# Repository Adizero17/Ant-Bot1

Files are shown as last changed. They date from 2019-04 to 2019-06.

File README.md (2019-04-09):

# Ant-Bot1
Hallo zusammen und Herzlich Willkommen bei unserem Hochschulprojekt Robots Wars!
In den kommenden Wochen werden wir einen Roboter der AntClass konstruieren und freuen uns dabei auf ein faires Battle mit unseren Kommilitionen.

# SolidWorks CAD-Komponenten
Im Verzeichnis CAD-Daten befinden sich einige SolidWorksBauteile bzw. Baugruppen von Zukaufteilen.

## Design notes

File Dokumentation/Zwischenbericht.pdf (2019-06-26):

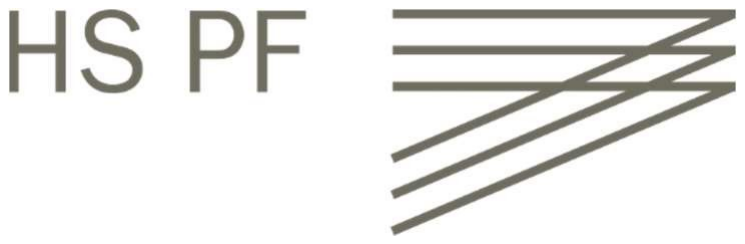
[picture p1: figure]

Projekt Methoden und Kreativität

# Gruppe IT-S3 – Robot Wars Zwischenbericht

Autoren: | Leon Frei – 314332 Tobias Schieler – 314689 Sven Krohn – 314695 Louis Scharr – 314538
Betreuer: | Prof. Alfred Schätter Dipl.-Wirt.-Ing. René Triebenstein
Ort: | Pforzheim
Abgabetermin: | 24.04.2019
Semester: | SS 2019

## Abbildungsverzeichnis

## Inhaltsverzeichnis

## 1 Einleitung

Das diesjährige Projekt der Veranstaltung „Projekt Methoden und Kreativität“ besteht darin, einen Roboter der Ant-Klasse mittels SolidWorks und 3D Druck zu entwickeln. Dieser Prozess wird durch verschiedene Meilensteine begleitet. Angefangen bei der Analyse, über das Konzept und den Prototyp, bis hin zur Fertigung und Präsentation des Endprodukts. Begleitend hierzu sollen die Meilensteile mittels einem Versionsverwaltungssystem kontrolliert und gesichert werden. Zusätzlich zur Analyse und der Entwicklung werden die jeweiligen Meilensteine dokumentiert, sowohl als auch präsentiert. Im folgenden Bericht soll dies dargestellt und erläutert werden.

## 2 Aufgabenstellung und Zieldefinition

Ziel des Projektes ist die Entwicklung und die Herstellung eines Miniatur Roboters der Ant-Klasse mithilfe von begrenzten Möglichkeiten in Material- und Werkzeugwahl. Der Roboter wird im CAD (SolidWorks) entwickelt und konstruiert und anschließend mittels einem 3D Drucker mit FDM-Technologie hergestellt. Dabei soll der Roboter weder die Gewichtsgrenze von 220g, noch die Größe von 10x10x10cm überschreiten. Dazu muss erwähnt werden, dass mögliche Anbauten für den Roboter (z.B. Waffen/Greifer) die Größenabmessungen in geringem Maße überschreiten dürfen. Ein zeitlicher Rahmen ist ebenfalls vorgegeben. Damit im Zusammenhang stehend soll am Ende des Projektzeitraumes ein Wettbewerb unter beiden teilnehmenden Gruppen stattfinden. Die Aufgabe hierbei ist es entweder 3 Tischtennisbälle in der Zone des Gegners zu platzieren, den Gegner bewegungsunfähig zu machen, oder ihn in die Falltür der Arena zu schieben. Um einerseits Versions-Probleme bei der Umsetzung mit dem 3D-Drucker zu vermeiden, als auch um einzelne Bauteile und Meilensteine des Projektes zu verwalten und zu sichern, wird das Versionsverwaltungstool GitHub verwendet, auf welches im späteren Verlauf des Berichts näher eingegangen wird.

## 3 Analyse

Im Folgenden werden alle beeinflussenden Komponenten des Projektes, die zu verwendenden Materialien, die Werkzeuge, die Informationsquellen so wie das Umfeld analysiert.

3.1 Aufgabenstellung
In erster Instanz wurde die gegebene Aufgabenstellung analysiert. Die Aufgabenstellung lautet wie folgt:

„Es soll ein Miniatur-Roboter entwickelt werden, der auf einem 3D Drucker der FDM- Technologie hergestellt werden kann. Dabei soll der Roboter max. 10x10x10cm groß sein und nicht mehr Gewicht als 220g auf die Waage bringen. Der Roboter wird per Fernsteuerung von seinem Piloten gesteuert und hat die Aufgabe seinen Gegner in der Arena bewegungsunfähig zu machen oder in eine der Fall-Türen der Arena zu schieben. Der Antrieb erfolgt über 2 Miniatur Getriebe-Motoren und einem 2S-Lipo-Akku. Die elektronischen Komponenten sind Zukaufteile und werden von der Hochschule gestellt.Der Contest findet bei der Endpräsentation statt.
Der Roboter wird im CAD entwickelt und konstruiert. Um Versions-Probleme bei der späteren Umsetzung mittels 3D-Drucker zu vermeiden soll schon von Projekt-Beginn an das Versionsverwaltungssystem Git die einzelnen Bauteile des Roboters versionieren und sichern.“ ¹

Die Aufgabenstellung beschreibt wie der Contest am Ende der Projektarbeit gewonnen werden kann. Einerseits kann gewonnen werden, indem alle drei Tischtennisbälle in der gegnerischen Zone platziert werden (Methode 1), der Gegner in die Falltür befördert wird (Methode 2), oder der Gegner bewegungsunfähig gemacht wird (Methode 3). Dies führt zu folgender Schlussfolgerung: um die Tischtennisbälle in die gegnerische Zone zu befördern, ist es notwendig eine Vorrichtung zur Befestigung der Bälle zu konstruieren. Diese kann entweder an der Front oder dem Heck des Roboters befestigt werden.

1 https://lms.hs-pforzheim.de/pluginfile.php/75548/mod_resource/content/15/PMK_Projekte_SS_2019.pdf

Methode 2 erfordert Anbauten, mithilfe derer der Gegner in die Falltür geschoben bzw. gedrängt werden kann. Die letzte Methode, Methode 3 erfordert einerseits ein bodenschlüssiges Design des eigenen Roboters, so dass der Gegner den eigenen Roboter nicht einfach weghebeln kann. Andererseits ist es notwendig „Waffen“ und Ersatzteile zu bauen/designen, nicht nur um den Gegner bewegungsunfähig zu machen, sondern auch um eventuell zerstörte Bauteile austauschen zu können.

Als nächster Punkt der Aufgabenstellung ist die Gewichtsbegrenzung zu berücksichtigen. Der Roboter darf maximal ein Gewicht von 220g aufweisen, daher muss zu aller erst berechnet werden, wie viel die bisher bereitgestellten Teile wiegen und wie viel Gewicht somit noch hinzugefügt werden kann. Auf der anderen Seite müssen die Auswirkungen der Gewichtswahl berücksichtigt werden. Ein leichter Aufbau ermöglicht ein schnelleres Manövrieren des Roboters, wobei ein schwerer Aufbau eventuelle Designoptionen ermöglicht und Angriffen des Gegners besser standhält.

Als letzter Punkt der Aufgabenstellung muss noch die Arbeit mit den verschiedenen Programmen (GitHub, SolidWorks) sowie der hohe Organisationsaufwand berücksichtigt werden. Hierbei ist es wichtig eine klare Aufgabenverteilung und einen Zeitplan zu entwickeln.

3.2 Informationsquellen
Bei der Analyse der Informationsquellen gibt es einige grundlegende Dinge, die beachtet werden müssen. Da es sich bei der Konstruktion des Roboters nicht wirklich um ein wissenschaftliches Thema handelt, gibt es hierzu auch keine Fachliteratur, die die Einarbeitung in das Thema erleichtert und eindeutige sowie fundierte Informationen liefert. Aus diesem Grund wurde bei der Informationsbeschaffung hauptsächlich auf Internetseiten zurückgegriffen.
Diese haben zwar den Vorteil, dass die Informationen leicht und schnell zugängig sind, jedoch nicht wissenschaftlich untermauert sind. Ein weiterer Punkt, der sich bei Analyse herausstellte, war dass der Hauptteil der Internetseiten auf Englisch ist. Dies erschwert die Beschaffung von Informationen, da es häufiger zu Verständnisproblemen aufgrund der Sprachbarriere kommen kann, was unter anderem natürlich auch auf das technische Thema und dessen Fremdwörter zurückzuführen ist.

3.2.1 Bildersuche per Google
Als eine erste Quelle zur Beschaffung von Informationen wurde die Google-Bildersucher verwendet. Dies diente hauptsächlich zur Erlangung von Designideen für den Roboter an sich, sowie das Chassi, die möglichen Anbauten sowie Waffen.

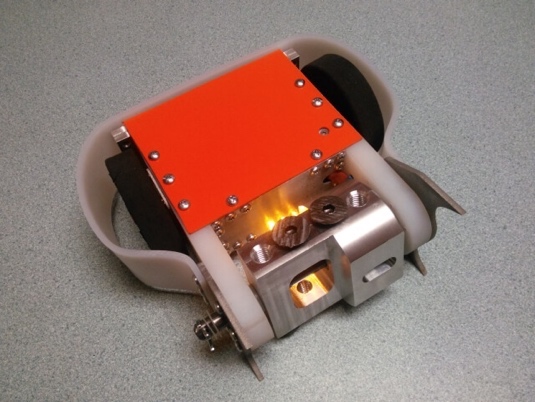
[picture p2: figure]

Abbildung 1: Designidee für Roboter ²
3.2.2 Foren
Eine weitere Informationsquelle waren Internetforen und Verbände (z.B. „German Roboteers Association“). Der Vorteil dieser Foren war vor allem die hohe Dichte an Beiträgen und Informationen rund um das Thema AntBots.

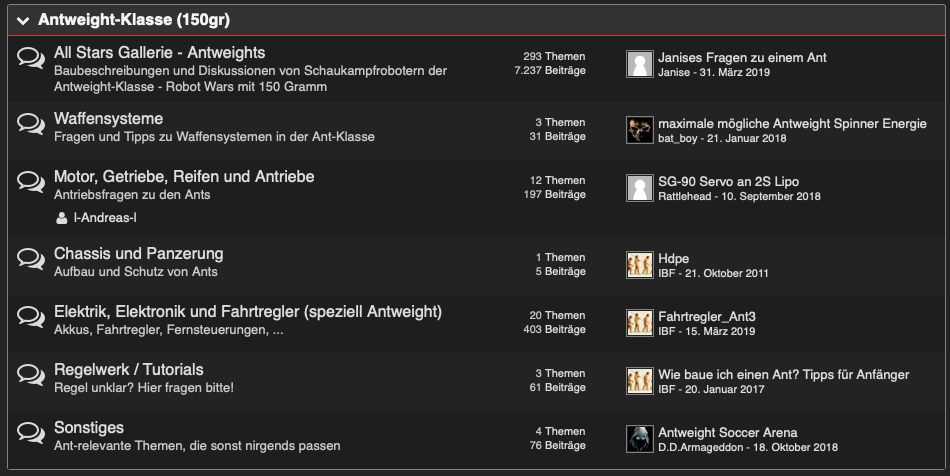
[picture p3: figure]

Abbildung 2: Internetseite German Roboteers Association ³

Die Informationen reichen von einer Galerie mit Designideen, über Beiträge zu den Motoren und der Chassis, bis hin zu speziellen Anleitungen zur Elektronik, gerade für die Ant-Klasse. Ein weiterer Vorteil ist natürlich, dass alle Daten frei zugänglich sind und man sich mit anderen, begeisterten AntBot-Entwicklern austauschen kann. Der Austausch an Informationen erfolgt hierbei sehr schnell, man profitiert außerdem von den Erfahrungen der anderen Entwickler.

2 https://combatrobotics.co.nz/wp-content/uploads/2018/04/3lb-Battle-Bot-Kit.jpg
3 http://forum.roboteers.org/index.php?board-list/&s=514eca6cca9b86eacb0dade5b4f5d3b127892d1e

3.2.3 Thingiverse

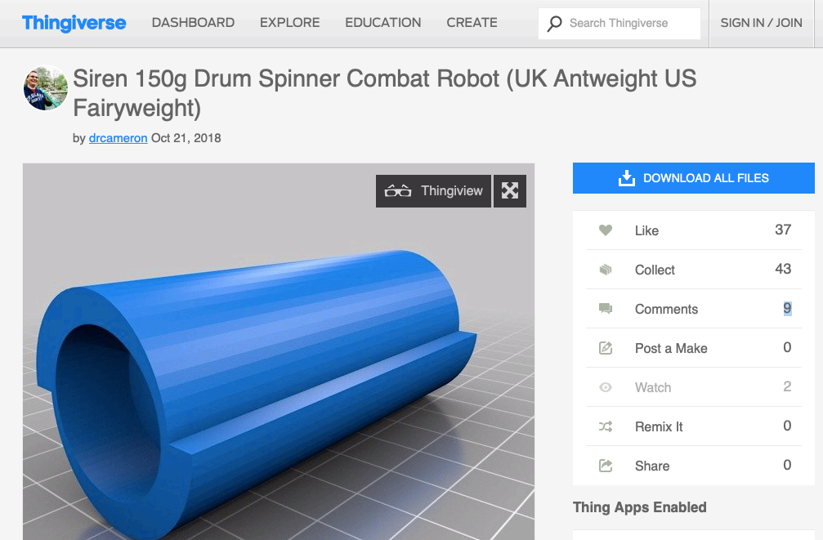
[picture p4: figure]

Abbildung 3: Beitrag zu AntBot auf Thingiverse ⁴
Die Internetseite Thingiverse hat sich als sehr umfangreiche Informationsquelle herausgestellt. Hier sind rund 50 Beiträge zum Thema AntBots zu finden, teilweise auch sehr detailliert. Was vor allem auffällt ist, dass nahezu jeder Beitrag ein Downloadfeld besitzt. Hierüber lassen sich alle angefertigten Zeichnungen als STL-Dateien herunterladen und nutzen. Der Download dieser Dateien ist kostenlos, allerdings besteht die Möglichkeit den Entwicklern eine Spende zukommen zu lassen. Des Weiteren wird auf den Zusammenbau der Roboter eingegangen, welche Teile benutzt wurden und auch wo diese zu erwerben sind. Teilweise werden zusätzlich sogar noch die Einstellungen des 3D-Druckers beschrieben, sowohl als die Verwendung des Materials mit Anwendungshinweisen.

3.2.4 YouTube
Als letztes Informationsmedium wurde die Plattform YouTube genutzt. Hier gibt es sogenannte Videoreihen mit „How to“ Anleitungen zu jedem Schritt der Entwicklung eines Ant-Klasse Roboters. Es wird in den einzelnen Videos auf die Bauweise, das Design, die Waffen sowie die Elektronik eingegangen. Der Vorteil ist natürlich das das Ganze visualisiert ist und man so einen besseren Bezug zum Thema findet.

4 https://www.thingiverse.com/thing:3168700

Es wird sehr ausführlich auf jedes Thema eingegangen, zudem sind Links zu allen Bauteilen angegeben. Auch hier besteht die Möglichkeit sich mit den Entwicklern in Verbindung zu setzen, um mehr über Informationen allgemein bzw. das Projekt zu erhalten. Außerdem ist auch bei mancher dieser Videoreihen die Möglichkeit gegeben, einzelne, bereits designte Teile herunterzuladen.

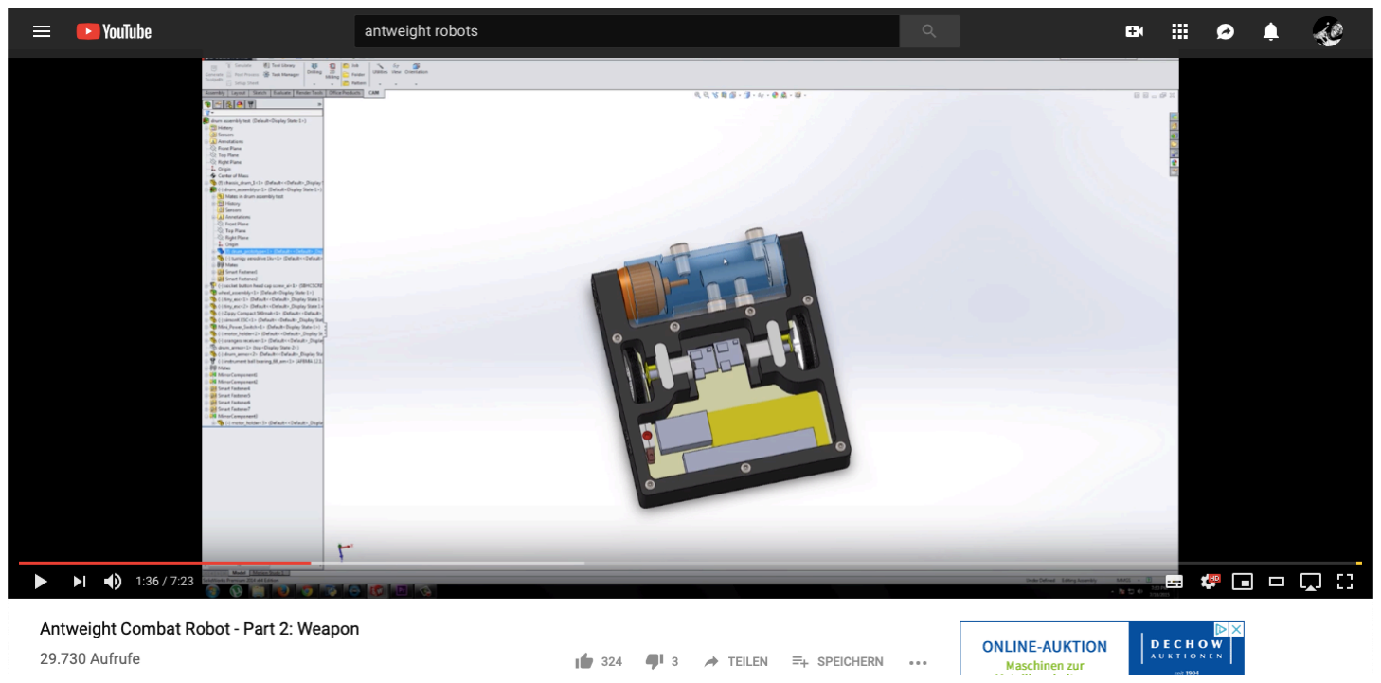
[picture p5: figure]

Abbildung 4: Video einer Videoreihe zum Aufbau eines AntBots ⁵

3.3 SolidWorks
SolidWorks ist ein Konstruktionsproramm, mit dem detaillierte Zeichnungen möglich sind. Hier können sowohl 3D- als auch 2D-Konstruktionen erstellt werden. Außerdem sind die generierten Dateiformate mit der Software des zur Verfügung gestellten 3D-Druckers kompatibel. Bauteile können im Programm direkt zu einer Baugruppen zusammengefügt werden und Änderungen werden hier auch direkt ersichtlich. Für den Windows User ist der Aufbau benutzerfreundlich gestaltet, da sich die Oberfläche an der Windows-Steuerung orientiert.⁶

3.4 GitHub
GitHub ist ein Onlinedienst, welcher über diverse Funktionen verfügt und zahlreiche Vorteile bezüglich eines Projektes, wie es das Konstruieren eines Ant-Roboters darstellt, bietet. Aus diesem Grund nimmt das Verwaltungstool Github im Projekt eine zentrale Rolle ein. Durch die öffentliche Bereitstellung von Daten und Depositories diverser Entwickler von der ganzen Welt kann man gezielt nach Anregungen und Ideen suchen.

5 https://www.youtube.com/watch?v=R5MbYqHyuIM&t=114s 6 https://www.solidworks.com/de

Man hat zudem die Möglichkeit, bereits konstruierte Teile als „.SLDPRT“ herunterzuladen, was das einfache Öffnen der Datei mit Programmen wie Solid Works ermöglicht. Hierdurch kann man, sollten die Teile den eigenen Ansprüchen gerecht werden, enorm an Zeit sparen. Github dient außerdem als Versionsverwalter von Projekten. Dies bedeutet, dass Backups und Zwischenstände von allen konstruierten Bauteilen erzeugt werden, sodass kein Datenverlust auftritt. Weiter dient es als Schnittstelle, was das Zusammenführen von Ergebnissen und das Sammeln aller relevanten Daten an einem Ort äußert komfortabel macht. Entwickler haben so, durch Absprechen und Arbeitsteilung, zudem die Möglichkeit gleichzeitig an einem Projekt zu arbeiten.

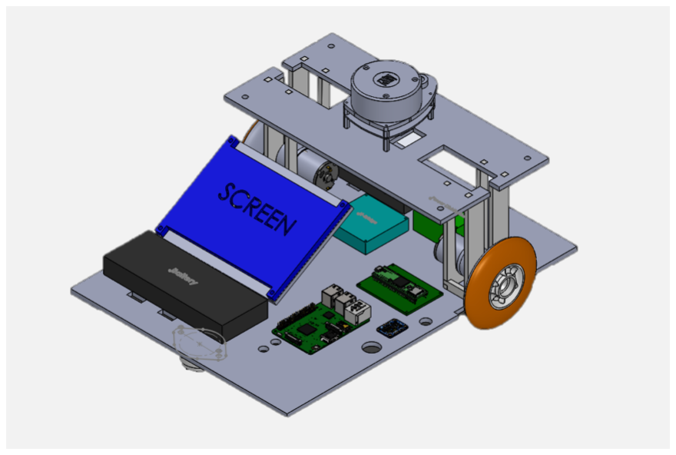
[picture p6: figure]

Abbildung 5: Auf Github hochgeladener Beispielhafter Roboter der Ant-Klasse ⁷

7 https://github.com/thedch/indoor-autonomous-system-cad/blob/master/RobotImages/RobotIsometric.png

3.5 Bauteile
Bei der Bauteilanalyse muss zwischen den elektrischen sowie den mechanischen Komponenten unterschieden werden. Die bisher bereitgestellten Bauteile sind zwei Gleichstrom Getriebemotoren, ein Speed Controller, zwei Pololu Räder und eine Stützkugel. Im Folgenden soll näher auf die einzelnen Bauteile eingegangen werden.

3.5.1 Gleichstrom Getriebemotor
Der Getriebemotor weißt eine Größe von 25x12x10 mm auf sowie ein Gewicht von 10 g. Zudem läuft der Motor unter einer Betriebsspannung von 6 V. Der Motor an sich ist ein Bürstenmotor und übergibt die Kraft an das Getriebe mit einer
Übersetzung von 1:200. Der Getriebetyp ist Metall. Die Kraft wird

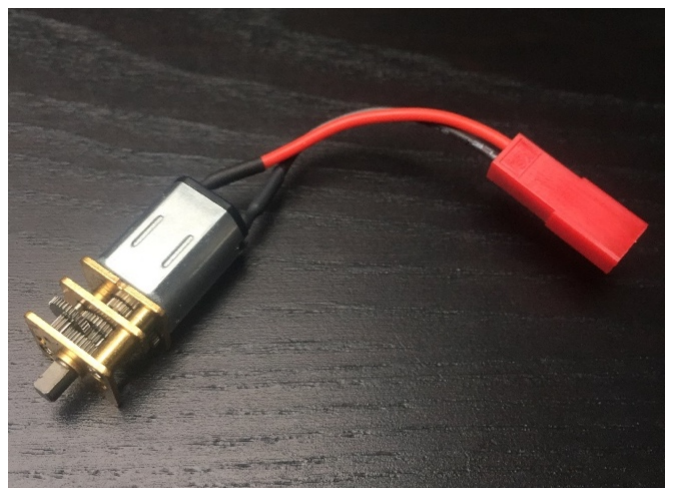
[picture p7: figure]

vom Getriebemotor an das Getriebe weitergegeben und dann in dabei in das Verhältnis 1:200 übersetzt. Diese Kraft wird dann weiter auf die Räder übertragen. ⁸

3.5.2 Micro Dual Bi-Directional Speed Controller

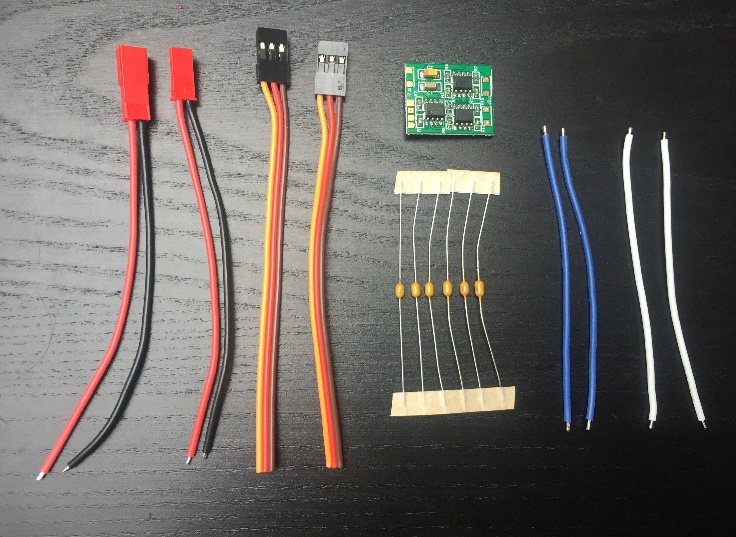
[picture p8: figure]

Abbildung 7: Speed Controller Quelle: eigene Aufnahme

8 https://eckstein-shop.de/V-TEC-Micro-DC-Motor-Gleichstrom-Getriebemotor-10x8mm-10x12mm-12x13mm-3V-6V-17-560RPM

Abbildung 6: Gleichstrom Getriebemotor Quelle: eigene Aufnahme

Der Speed Controller weißt eine Größe von 19x23x5 mm auf und ein Gewicht von 6 g. Zudem besitzt der Speed Controller und einer Eingangsspannung zwischen 4,2 V – 9,6 V sowie eine Stromstärke von 6 A.
Die elektronische Spannungsregelung liegt bei 5V1A. Die PWD-Frequenz beträgt 250 Hz. ⁹
Diese Platine besitzt einen Mischer, mit dem es möglich ist den Roboter mit einer Fernbedienung zu steuern. Das Signal (siehe Abbildung 7) bestimmt hier Motordrehzal (vorwärts/rückwärts), das Signal 2 die Richtung (links/rechts). ¹⁰

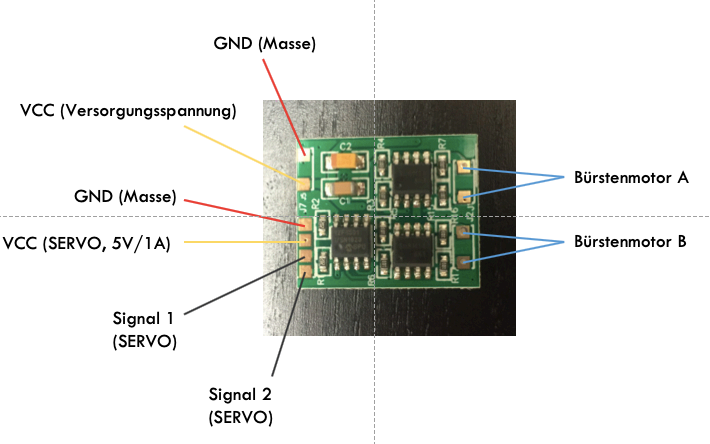
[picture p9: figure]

Abbildung 8: Platine

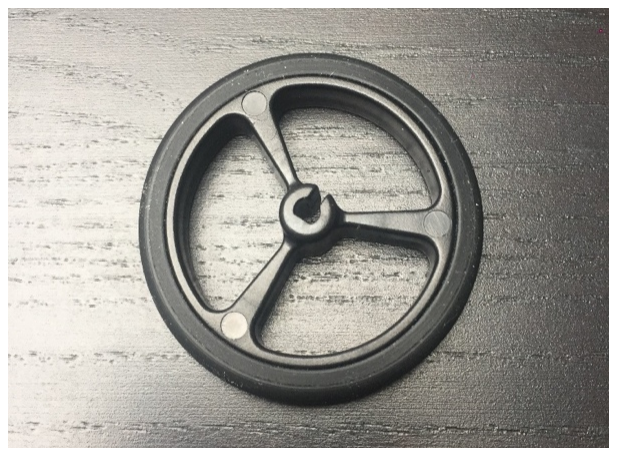
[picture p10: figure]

3.5.3 Pololu Rad
Insgesamt wurden 2 Pololu Räder zu Verfügung gestellt. Sie weißen beide eine Größe von 40x7 mm auf sowie ein Gewicht von jeweils 4 g. Die Räder sind Kunststoff gefertigt und mit Silikon besetzt. Sie dienen der Fortbewegung des AntBots. ¹⁰

9 https://www.banggood.com/2S6A-Micro-Dual-Bi-Directional-Speed-Controller-for-Tank-Crawler-and-Boat-without-Brakep-1032413.html?ID=520184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 10 https://github.com/merlin1031/AntBots-2019

Abbildung 9: Pololu Rad
Quelle: eigene Aufnahme

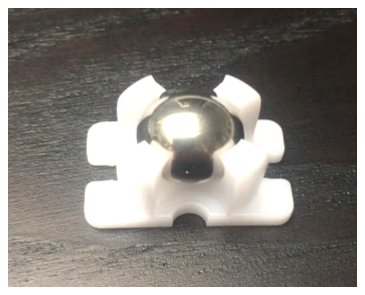
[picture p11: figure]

3.5.4 Stützkugel
Das letzte, bereitgestellte Bauteil ist die Stützkugel bzw. eine Kugelrolle. Sie weißt eine Größe von 24x16x16 mm auf und wiegt 9 g. Sie ist aus Metall gefertigt und dient als Stützkugel/Stützrad für den AntBot. ¹⁰

3.6 Fertigungsverfahren
3.6.1 Löten
Da für den Aufbau und die Funktionsweise des Roboters eine Platine benötigt wird, ist es notwendig bestimmte Teile zu löten. Das Löten ist ein thermisches Verfahren, bei dem Werkstoffe stoffschlüssig zusammengefügt werden. Der Unterschied zum Schweißen besteht hierbei, dass die Liquidustemperatur der beiden zu verbindenden Komponenten nicht überschritten werden darf. Insgesamt gibt es drei verschiedene Lötarten: das Weichlöten (Liquidustemperatur bis 450 Grad Celsius), das Hartlöten (über 450 Grad Celsius) und das Hochtemperaturlöten (mehr als 900 Grad Celsius). Für das Projekt des AntBots wird das Weichlötverfahren genutzt. Beim Löten muss darauf geachtet werden, dass die Lötstellen sauber sind und dass ebenfalls keine Lotreste außerhalb der Lötstellen festsitzen. Außerdem sollte nicht zu viel Lot verwendet werden, aber auch nicht zu wenig, da sonst die Funktionsweise der Platine beeinträchtigt werden kann. Als letztes sollten auch keine kalten Lötstellen entstehen, da auch hier keine stoffschlüssige Verbindung zwischen Lot und Fügepartner entsteht. ¹¹

3.6.2 3D-Druck

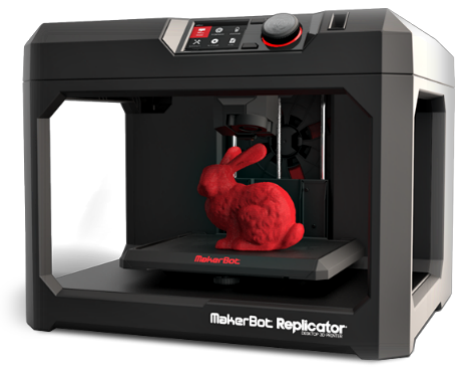
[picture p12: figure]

Abbildung 11: Makerbot 5th Generation ¹²

11 http://www.gasloetkolben.com/welche-loetarten-gibt-es/ 12 https://www.3dhubs.com/s3fs-public/Makerbot%20Replicator%205th%20Gen%202.png

Abbildung 10: Stützkugel
Quelle: eigene Aufnahme

Für die Herstellung einzelner Bauteile steht der Makerbot 5th Generation (Abb. 10) zur Verfügung. Hierbei handelt es sich um einen 3D- Drucker mit einem Düsendurchmesser von 0,4 mm. Durch die Begrenzung des Bauteils auf 10x10x10 cm besteht keine Gefahr beim Drucken an die maximale Bauraumgröße mit 25x20x15 cm des 3D-Druckers zu geraten.

Sollte ein sehr filigranes oder optisch hochauflösendes Bauteil für die Konstruktion des AntBots von Nöten sein, kann die Schichtdicke von 0,1 mm auf 0,01 mm heruntergefahren werden.
Als Datengrundlage kann der Makerbot 5th Generation sowohl STL, OBJ, THING als auch Makerbot Dateien verarbeiten. Lediglich alte Dateitypen wie X3G lassen sich leider nur sehr aufwendig konvertieren und sind dann immer noch nicht sehr kompatibel.

Vor dem Druck müssen die über SolidWorks erstellten Bauteile in einer von Makerbot zur Verfügung gestellten Software hochgeladen und vorbereitet werden. Hierbei wird zum Beispiel Stützmaterial für den Druck in das Bauteil eingefügt. Am Drucker selbst besteht die Möglichkeit über USB, WLAN oder LAN zu drucken, was eine Flexibilität darstellt. Als weiterer Vorteil ist zu sagen, dass der Makerbot 5th Generation erkennt, wenn Filament ausgeht und daraufhin der Druck direkt gestoppt wird. So kann es in diesem Bereich zu keinen Komplikationen kommen.
Für die Fertigung ist auch die überdurchschnittliche Verfahrenszeit zu berücksichtigen. Hier muss darauf geachtet werden, dass frühzeitig mit einem Druck begonnen wird. ¹³ ¹⁴

13 https://www.pcwelt.de/produkte/Makerbot-Replicator-Fuenfte-Generation-im-Test-3D-Drucker-9692579.html 14 https://3ddrucker.de/shop/pi.php/MakerBot-3ddrucker/MakerBot-Replicator-5th-Generation/3D-Drucker-MakerBot-Repli-

cator-5-Generation.html

3.6.3 Laserschneiden
Zusätzlich zum 3D-Drucker besteht auch die Möglichkeit zur Verwendung eines Laserschneiders. Nahezu jeder Werkstoff lässt sich mithilfe des Laserstrahles schneiden, hinzu kommt die hohe Präzision des Lasers. Je nach Werkstoff wird ein anderes Verfahren verwendet. Es wird zwischen dem Laserschmelzschneiden, dem Laserbrennschneiden und dem Lasersublimierschneiden unterschieden. Der beim Schneiden entstehende Schneidspalt ist nur minimal größer als der Laserstrahl selbst, womit sich Toleranzen von +/- 0,1 mm/m erzielen lassen. Ebenfalls abhängig von der Dicke des Materials sowie dem Werkstoff an sich ist die Schnittgeschwindigkeit von bis zu 40 m/min. ¹⁵

3.6.4 Kleben
Ebenso wie das Löten, ist das Kleben ein Fügeverfahren. Beim Kleben werden zwei Werkstoffe stoffschlüssig miteinander verbunden. Eine entscheidende Rolle hierbei spielt die Benetzung der zu klebenden Oberflächen. Ebenfalls zu berücksichtigen sind Adhäsion und Kohäsion. Adhäsion bezeichnet die Haftkräfte an den Kontaktflächen der zu klebenden Stoffe, wobei Kohäsion die Summe der Bindekräfte zwischen den einzelnen Molekülen des Klebers beschreibt. Eine ideale Klebeverbindung ist gegeben, wenn beide diese Faktoren in etwa gleich groß sind.¹⁶

## 4 Konzept

Um generell ein Projekt jeglicher Art zu realisieren, ist es stets enorm wichtig, zunächst die Aufgabenstellung, sowie die Rahmenbedingungen klar zu definieren und sich diese vor Augen zu führen. Ohne diesen Schritt läuft man Gefahr, bestimmte Richtlinien zu missachten oder schlicht nicht das volle Potential seiner Ideen auszuschöpfen. Zudem ist es unabdinglich, sich seiner Möglichkeiten und Ressourcen bewusst zu sein. Basierend auf diesen Daten lässt sich mithilfe verschiedener Instrumente ein Konzept erstellen, welches eine ideale Ausgangslage für einen optimalen Projektablauf gewährleistet.

15 https://www.laserschneiden-marktplatz.de/laserschneiden-grundlagen 16 https://www.fachwissen-technik.de/verfahren/kleben.html

Da es sich beim Erstellen eines Roboters der Ant-Klasse um ein sehr technisches Projekt mit einem hohen Fokus auf das Themengebiet der Konstruktion handelt, ist es enorm wichtig, alle Schritte gut zu planen, um möglichst effizient und effektiv zu arbeiten. Um diesen Ansprüchen nachzukommen, wurden zunächst alle potentiellen Möglichkeiten für den Aufbau des Roboters mit Hilfe des morphologischen Kastens erfasst. Durch die visuelle Veranschaulichung aller Ausprägungen und Parameter ist es wesentlich einfacher, den für die jeweiligen Anforderungen perfekten Aufbau eines Projektes zu wählen.

5.1 Antriebskonzept

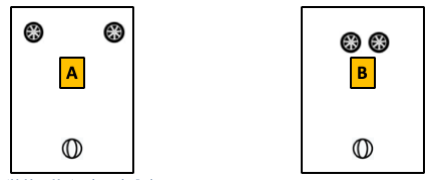
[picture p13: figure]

Abbildung 12: Anordnung der Räder
Quelle: eigene Darstellung
Für den Antrieb des Ant-Roboters sind neben den Elektronikbauteilen vor allem die beiden Räder und das Kugellager, welches als drittes Rad dient, relevant. Durch diese Bauteile findet letztendlich die Energieübertragung der elektronischen Bauteile auf den Untergrund statt. Der Antrieb des Roboters erfolgt, wie bereits erwähnt, durch zwei Elektromotoren, welche mit den Rädern verbunden sind, um eine Kraftübertragung zu realisieren. Um ein optimales Handling und Steuern des Roboters zu gewährleisten, wird das Kugellager (drittes Rad) am hinteren Teil des Roboters platziert. Der vordere Teil des Roboters wird dementsprechend dadurch definiert, dass an ihm die beiden normalen Räder montiert sein werden. Dieser Aufbau des Roboters mit Frontantrieb durch die beiden Räder vorne und einem Stützrad hinten ermöglicht es, den Roboter mit maximaler Kontrolle zu steuern. Bei der Positionierung der beiden Räder ist es besonders wichtig, einen optimalen Abstand zwischen diesen zu realisieren. Montiert man die beiden Räder, wie bei Abbildung 12 B zu nah aneinander, leidet nicht nur das Gleichgewicht des Roboters darunter.

Es wird ebenfalls weitaus schwerer, diesen zu steuern, da vor allem das Fahren von Kurven, aufgrund des kleineren Wendekreises ein Problem darstellen würde. Eine leicht eingerückte Lage der Reifen gewährleistet eine optimale Stabilität, Bodenhaftung, sowie das einfachste Steuern des Roboters. Zudem bietet dies Schutz vor potentiellen Angriffen des anderen Roboters, da die Räder mitunter eine der größten Schwachstellen darstellen. Das Stützrad, welches sich am hinteren Teil befinden wird, sollte natürlich idealerweise zentral positioniert sein, um ein gleichmäßiges Lenkverhalten zu ermöglichen.

Die Räder werden direkt mit den beiden Elektromotoren verbunden sein. Dies bedeutet im Umkehrschluss, dass eine Konstruktion die beiden Motoren fixieren muss, um eine optimale Stabilität zu erreichen. Diese Konstruktion wird voraussichtlich mit den Motoren verschraubt.

5.2 Lage des Akkus und der Elektrokomponenten

Wie bereits in der Analyse beschrieben, wird der Roboter über zwei Elektromotoren verfügen, welche den Roboter antreiben und einen weiteren Elektromotor, welcher für die Funktion etwaiger Zusatzanbauten benötigt wird. Ferner wird ein Akku im Roboter montiert sein und eine Platine, welche die Programmierung des Roboters beinhaltet und die Steuerung mit Hilfe einer Fernsteuerung ermöglicht. Dadurch, dass der Roboter auf einer Seite eine V-Form mit dem Zweck der Ballführung aufweisen wird, ist eine Wahl der Lage der elektronischen Komponenten nur im mittleren Bereich, bzw. auf der anderen Seite der Ballführung möglich.

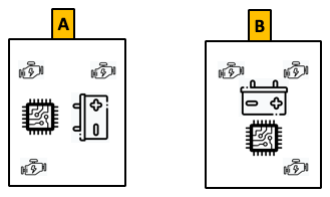
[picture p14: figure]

Abbildung 13: Lage des Akkus und der Elektrokomponenten Quelle: eigene Darstellung

Die beiden Elektromotoren, welche die Räder antreiben habe natürlich ihre feste Position. Lediglich bei der Platzierung des Akkus, sowie der Platine herrscht eine gewisse Freiheit. Um die Stabilität des Roboters nicht einzuschränken, ist es zunächst wichtig, die beiden Bauteile so zu platzieren, dass eine gleichmäßige Gewichtsverteilung herrscht. Da der Akku mit 35 Gramm etwas schwerer ist als die Platine, sollten beide Bauteile auf einer Linie angeordnet sein, wie in Abbildung 13B zu sehen ist. Fixiert werden der Akku und die Platine auf der Grundplatte, welche die Basis des Roboters darstellt. Wichtig für die Positionierung des Akkus ist es, die Möglichkeit zu besitzen, diesen zu wechseln.

Dies bedeutet, dass der Akku durch keine Kabel oder Bauteile verdeckt sein darf, um ein leichtes ein- und ausbauen zu ermöglichen. Das letzte Elektronikbauteil stellt den Antrieb für den Zusatzanbau dar, welches möglichst nahe an diesem montiert sein sollte, um ein kompliziertes Innenleben des Roboters zu vermeiden.

5.3 Chassis-Formen und Ballführung
Die Chassis Form ist womöglich der wichtigste Bestandteil des Konzeptes, da sie die Basis des Roboters darstellt. Sie besteht aus der Grundplatte, welche die Fixierung der elektrischen Bauteile ermöglicht, sowie den Wänden und dem Innenleben, welche für Stabilität sorgen und Schutz vor dem gegnerischen Roboter bieten. Ein weiterer wichtiger Parameter, welcher auf keinen Fall vernachlässigt werden darf, ist das Gewicht des Roboters, welches auf 220g limitiert ist. Aufgrund dessen ist es enorm wichtig, so wenig Material wie möglich für die Grundplatte aufzuwenden. Eine Konstruktion der Grundplatte mit Rillen und dünnen „Stäben“, anstatt einer vollausgefüllten Fläche ist die logische Konsequenz dieser Überlegung. Da man später in der Lage sein soll, wie in „1.2 Lage der Elektrokomponenten“ bereits beschrieben, den Akku zu wechseln, bietet eine Steckverbindung zum Verschluss des Rahmens eine optimale Lösung.
Wie in der Analyse der Aufgabenstellung beschrieben, wird der Roboter in der Lage sein einen Ball zu führen und von Punkt A nach Punkt B zu „transportieren“. Dies bedeutet, dass die Grundplatte die Form einer Ballführung aufzeigen wird. Die simpelste Möglichkeit eine Führung für einen Ball zu realisieren, ist es, eine Art „V-Form“ zu erzeugen.

Diese soll den Vorteil einer Fixierung durch wenig Spielraum bieten und ein Verlust des Balles während der Roboter in Bewegung ist, vermeiden. Grundsätzlich hat man die Möglichkeit eine solche Form auf beiden Seiten des Roboters einzuplanen. Da jedoch nur in eine Richtung effektiv beschleunigt werden kann, würde es wenig Sinn machen, auf der Rückseite eine solche Form zu realisieren.

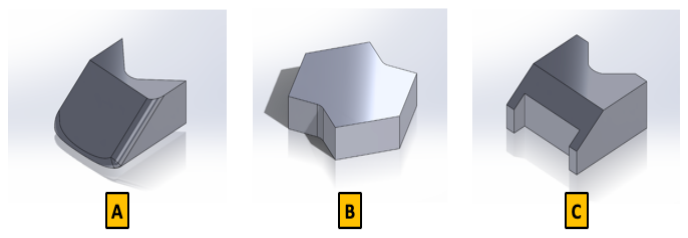
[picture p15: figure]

Abbildung 14: Chassis-Formen und Ballführung
Quelle: eigene Darstellung
Neben der Ballführung wird es eine Zusatzanbaute geben, welche zum Ziel haben wird, den gegnerischen Roboter auszuschalten. Da für den Zusatzanbau verschiedene Möglichkeiten zur Auswahl stehen, sehen dementsprechend auch die Chassis der Roboter-Modelle verschieden aus. Wichtig ist, dass die Fläche, an welcher später der Zusatzanbau angebracht sein wird, schon die zur optimalen Montage vorgesehen Form bietet.

5.4 Zusatzanbauten

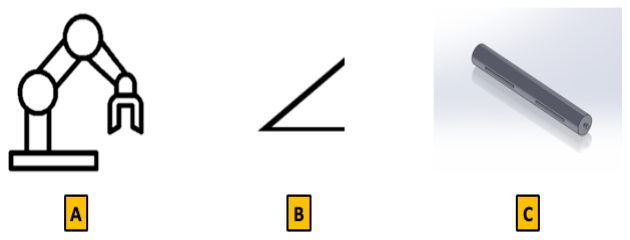
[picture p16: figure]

Abbildung 15: Möglichkeiten der Zusatzanbauten Quelle: eigene Darstellung

Der Zweck des Zusatzanbaus soll es vor allem sein, den Gegner durch eine gezielte Bewegung auszuschalten oder bewegungsunfähig zu machen. Nachdem auch hier durch brainstormen und Erstellung des morphologischen Kastens einige Ideen gesammelt und mögliche Konzepte betrachtet wurden, ließen sich letztendlich drei Konstruktionen herausfiltern. Der wohl vielversprechendste Ansatz ist eine Rolle (Abbildung 15C) mit abstehenden Ausprägungen, welche mit einem elektrischen Motor zur Rotation gebracht werden soll.

Eine dazu passende Chassis-Form ist in Abbildung 14C zu sehen. Diese Rolle bietet vor allem den Vorteil, bei schneller Rotation eine hohe Zerstörungskraft zu entfalten. Zudem ist der Einbau relativ simpel und platzsparend. Leider muss die Rolle relativ schwer sein, um wirklich in der Lage sein zu können, beim Gegner Schaden anzurichten.

Eine weitere Möglichkeit wäre, wie in Abbildung 15B zu sehen ist, eine Art Rampe zu entwerfen, welche den Gegner umwerfen soll. Die dritte Option ist ein Greifer, welcher sowohl dazu eingesetzt werden kann, den Gegner anzugreifen, wie auch den Ball zu greifen und zu transportieren.

5.5 CAD-Entwurf

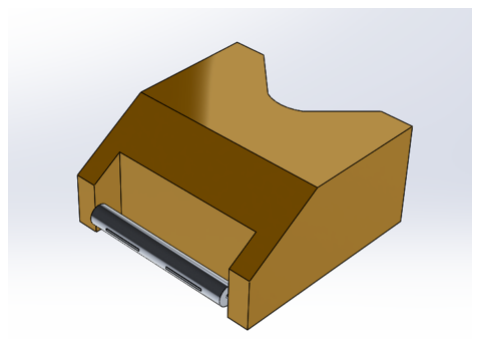
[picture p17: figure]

Abbildung 16: CAD-Entwurf
Quelle: eigene Darstellung
Nachdem anhand des morphologischen Kastens jeweils die besten Ausprägungen und Parameter gewählt wurden, ergibt sich für den Roboter das auf Abbildung 16 zu sehende Konzept. Der Entwurf wurde in Solid Works realisiert und lässt auf der Vorderseite des Roboters die Ballführung erkennen, welche die bereits beschriebene V-Form aufweist. Auf der Rückseite befindet sich die Rolle mit Ausprägungen, welche als Waffe dienen soll.

## 6. Fazit

Die wohl größte Schwierigkeit beim Konzept war die Erarbeitung der Zusatzanbauten mit Einbeziehung des Maximalgewichtes. Da durch die Elektronikbauteile, sowie die Chassis-Formen bereits ein beträchtlicher Teil des Gewichtes in Anspruch genommen wird, ist man bei der Konstruktion des Zusatzanbaus bereits eingeschränkt. So liegt das Hauptaugenmerk bei der Teileanfertigung stets auf möglichst geringer Materialaufwendung.

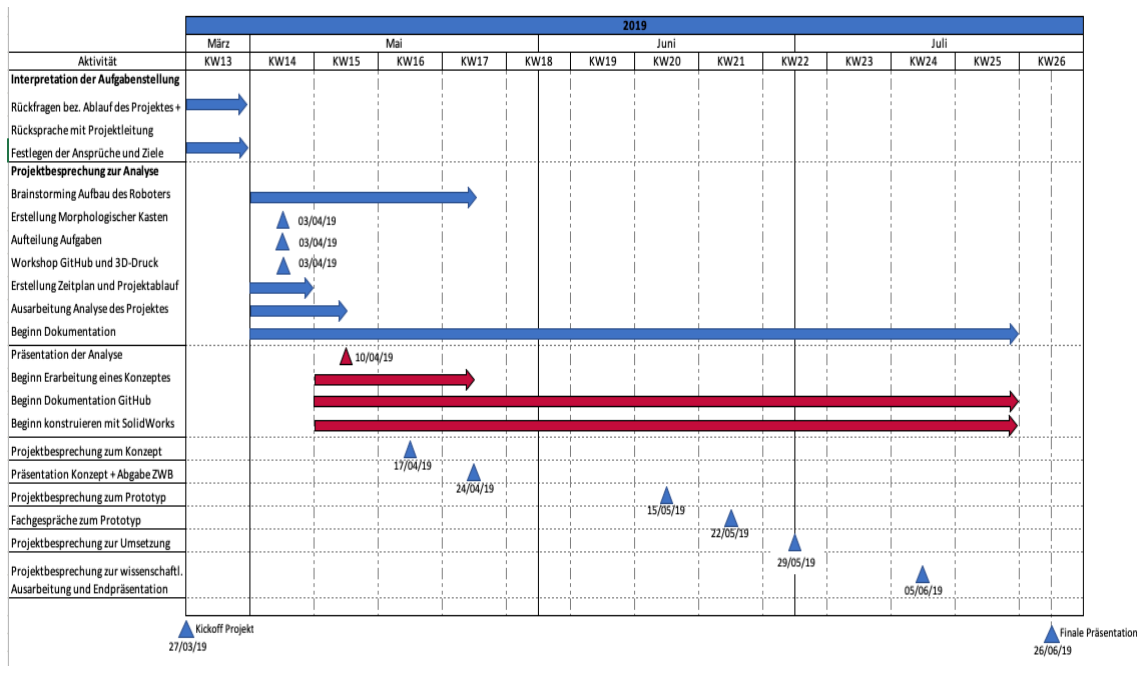
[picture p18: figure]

Abbildung 17: Zeitplan des Projektes
Quelle: eigene Darstellung
Im weiteren Projektverlauf wird basierend auf dem hier beschriebenen Konzept ein erster Prototyp mit Hilfe des 3D Druckes realisiert. Parallel findet die Konstruktion weiterer Bauteile in Solid Works inklusive Dokumentation auf GitHub statt. Außerdem wird begonnen, sich in weitere Fertigungsverfahren, wie z.B. das Löten einzuarbeiten.

## Literaturverzeichnis

[1] Prof. Alfred Schätter, „Hochschule Pforzheim – Moodle – BAE3250“, https://lms.hspforheim.de/pluginfile.php/75548/mod_resource/content/15/PMK_Projekte_SS_2019.pdf, [Online], 21.04.2019
[2] Combat Robotics, „Battle Bot Kit“, https://combatrobotics.co.nz/wp-content/uploads/2018/04/3lb-Battle-Bot-Kit.jpg, [Online], 21.04.2019
[3] German Roboteers Association, „Forum“, http://forum.roboteers.org/index.php?board-list/&s=514eca6cca9b86eacb0dade5b4f5d3b127892d1e, [Online], 21.04.2019
[4] Thingiverse, „Siren 150g Drum Spinner Combat Robot“, https://www.thingiverse.com/thing:3168700, [Online], 21.04.2019
[5] Robert Cowan, „YouTube - Antweight Combat Robot - Part 2: Weapon“, https://www.youtube.com/watch?v=R5MbYqHyuIM&t=114s, [Online], 21.04.2019
[6] DASSAULT S4STEMES, „Solid Works“, https://www.solidworks.com/de, [Online], 21.04.2019
[7] Adam Ames, „GitHub“,
https://github.com/thedch/indoor-autonomous-system-cad/blob/master/RobotImages/RobotIsometric.png, [Online], 21.04.2019
[8] Eckstein Komponente, “Eckstein-Shop”, https://eckstein-shop.de/V-TEC-Micro-DC-Motor-Gleichstrom-Getriebemotor-10x8mm-10x12mm-12x13mm-3V-6V-17-560RPM, [Online], 21.04.2019
[9] Banggood, “Banggood.com”, https://www.banggood.com/2S6A-Micro-Dual-Bi-Directional-Speed-Controllerfor-Tank-Crawler-and-Boat-without-Brake-p-1032413.html?ID=520184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, [Online], 21.04.2019
[10] René Triebenstein, “GitHub”,
https://github.com/merlin1031/AntBots-2019, [Online], 21.04.2019
[11] WordPress, „Gasloetkolben im Test“, http://www.gasloetkolben.com/welche-loetarten-gibt-es/, [Online], 21.04.2019

[12] 3DHubs, „Makerbot 5th Generation“, https://www.3dhubs.com/s3fs-public/Makerbot%20Replicator%205th%20Gen%202.png, [Online], 21.04.2019
[13] PCWelt, „Makerbot Replicator Fünfte Generation im Test“, https://www.pcwelt.de/produkte/Makerbot-Replicator-Fuenfte-Generation-im-Test-3D-Drucker-9692579.html, [Online], 21.04.2019
[14] 3DDrucker.de, „MakerBot 5th Generation“, https://3ddrucker.de/shop/pi.php/MakerBot-3ddrucker/MakerBot-Replicator-5th-Generation/3D-Drucker-MakerBot-Replicator-5-Generation.html, [Online], 21.04.2019
[15] Laserschneiden Marktplatz, „Grundlagen und Einordung der Laserschneidtechnik“,
https://www.laserschneiden-marktplatz.de/laserschneiden-grundlagen, [Online], 21.04.2019
[16] Fachwissen Technik, „Kleben“, https://www.fachwissen-technik.de/verfahren/kleben.html, [Online], 21.04.2019

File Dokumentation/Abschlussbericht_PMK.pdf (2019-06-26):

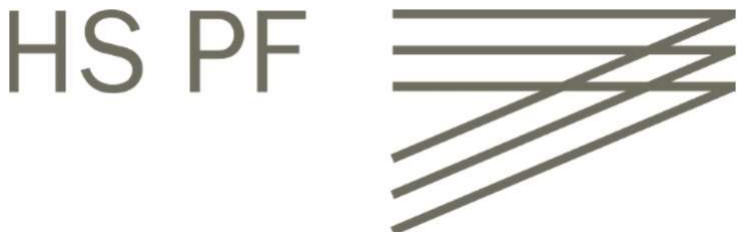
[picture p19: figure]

Projekt Methoden und Kreativität

# Gruppe IT-S3 – Robot Wars

# Abschlussbericht

Autoren: | Leon Frei – 314332 Tobias Schieler – 314689 Sven Krohn – 314695 Louis Scharr – 314538
Betreuer: | Prof. Alfred Schätter Dipl.-Wirt.-Ing. René Triebenstein
Ort: | Pforzheim
Abgabetermin: | 26.06.2019
Semester: | SS 2019

## Abbildungsverzeichnis

Abbildung 1: Konzept | 4
Abbildung 2: Prototyp | 5
Abbildung 3: Grundkörper Prototyp | 6
Abbildung 4: Verbauung der Walze | 6
Abbildung 5: Zusatzanbau Walze Prototyp | 7
Abbildung 6: Leichtbau des Grundkörpers | 8
Abbildung 7: Radkasten Draufsicht | 8
Abbildung 8: Überarbeitetes Konzept der Walze | 9
Abbildung 9: Überarbeitetes Konzept Innenleben Walze | 10
Abbildung 10: Stützring | 10
Abbildung 11: Altes Konzept Innenleben Walze | 10
Abbildung 12: Finaler Roboter der Ant-Klasse | 13
Abbildung 13: Explosionszeichnung Endergebnis | 15
Abbildung 14: Elektronischer Schaltplan | 16

## Tabellenverzeichnis

Tabelle 1: Gewichtsübersicht | 11
Tabelle 2: Gewichtsübersicht nach Überarbeitung der Bauteile | 12

## Inhaltsverzeichnis

## 1 Einleitung

Das Projekt der Veranstaltung „Projekt Methoden und Kreativität“ bestand darin, einen Roboter der Ant-Klasse zu entwickeln. Der Roboter unterstand dabei Bemaßungsgrenzen von 10x10x10 cm und einer Gewichtsgrenze von 220 g. Der abschließende Wettkampf soll hierbei entweder durch die Kampfunfähigkeit des Gegners oder der Platzierung dreier Tischtennisbälle im gegnerischen Feld gewonnen werden. Im folgenden Bericht wird die Umsetzung des Ant-Bots auf der Grundlage des Konzeptes und des Prototyps, der Verbesserungsprozess sowie der fertige Roboter dargestellt und erläutert.

## 2 Entwicklung des Roboters

2.1 Konzept

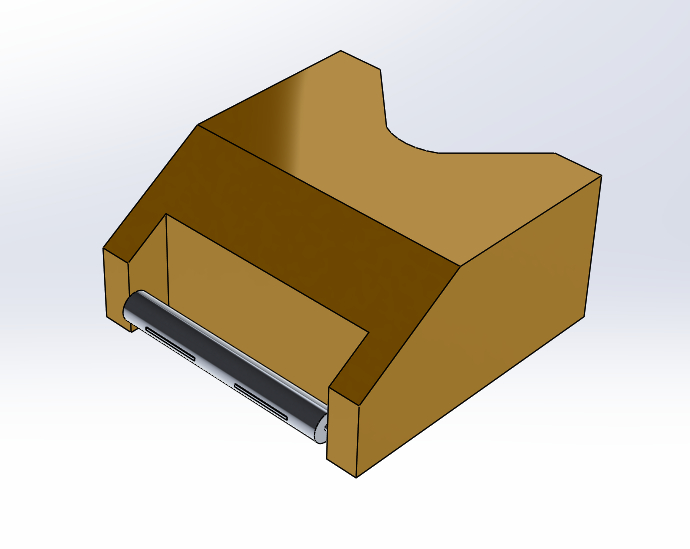
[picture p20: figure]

Abbildung 1: Konzept
Das Konzept diente als Grundlage für die Phase der Umsetzung bzw. für die Entwicklung des Prototyps. Bei der Entwicklung des Konzeptes wurden die ausgewählten Ausprägungen des morphologischen Kastens (siehe Anhang) umgesetzt. Bei der Ballführung wurde eine Dreiecksform mit einer Rundung kombiniert, um den Ball einerseits besser einfangen zu können und andererseits mithilfe der Rundung sicher führen zu können. Als Zusatzanbau wurde ein drehendes Element gewählt, welches als Walze zu erkennen ist (Abb. 1).

Der Verbau der Räder und des Stützrades ist in Abb. 1 nicht zu erkennen, jedoch wurde sich darauf geeinigt die Stützkugel hinten und die Polulu-Räder vorne anzuordnen, um so den Schwerpunkt nach hinten zu versetzen. Bei der Gewichtsbegrenzung wurde sich für die schwerste Variante entschieden, aufgrund des höheren Gewichts des Zusatzanbaus (Walze) und, um eine bessere Bodenhaftung zu erhalten.

2.2 Prototyp

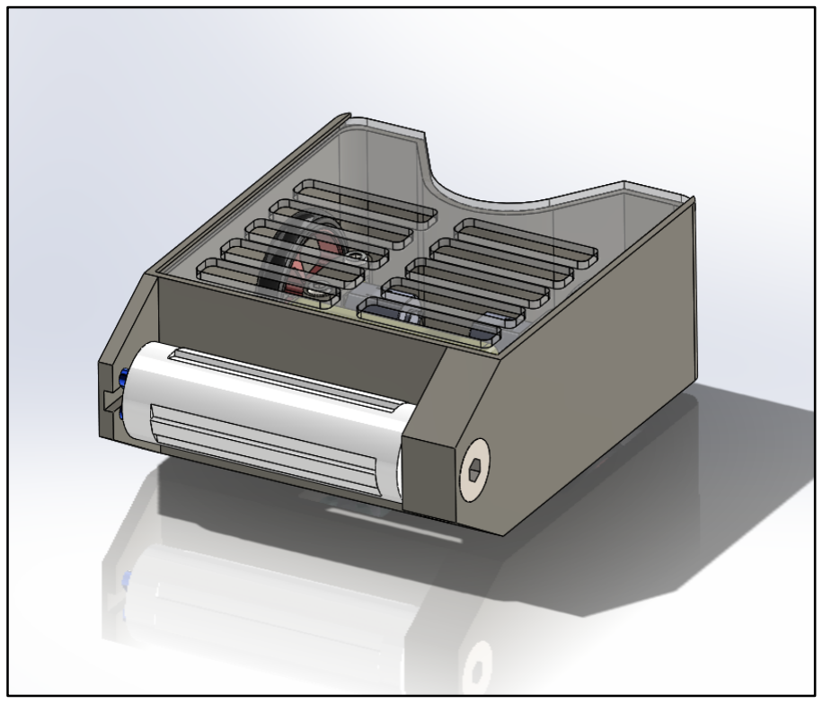
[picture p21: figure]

Abbildung 2: Prototyp
In Abb. 2 ist der komplette Prototyp inklusive des Zusatzanbaus zu sehen. Im Folgenden wird näher auf die einzelnen Teile des Prototyps, wie den Grundkörper, den Deckel und die Walze eingegangen und beschrieben, wie und warum diese so konstruiert wurden. Im Bild ist auch der Deckel zu sehen, der mit Einlässen versehen wurde, um einerseits für genug Kühlung des Akkus und der Motoren zu sorgen, außerdem um Gewicht zu sparen.

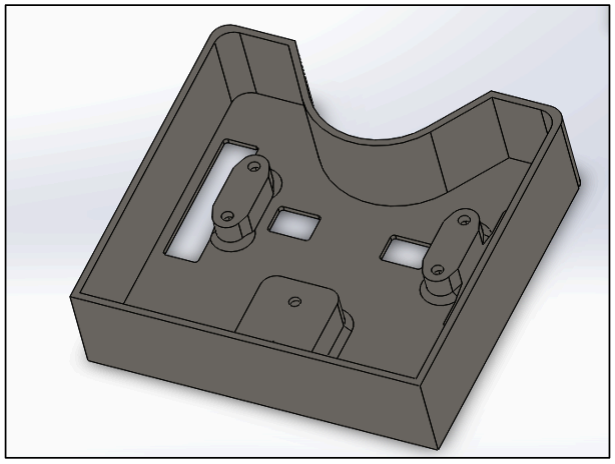
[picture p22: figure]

Abbildung 3: Grundkörper Prototyp
Abb. 3 zeigt den Grundkörper des Prototyps. Zu erkennen sind die Aussparungen für die Polulu-Räder mit entsprechender Befestigung für die beiden Getriebemotoren. Diese werden mit einer Halterung von oben mit einer M4-Schraube und einer Mutter auf der anderen Seite verschraubt. Am unteren Teil des Grundkörpers ist ebenfalls die Halterung für die Stützkugel zu erkennen. Diese wird mittels einer Presspassung von unten im Grundkörper fixiert. Die Ballführung im oberen Teil der Abbildung hat sich seit dem Konzept nicht verändert, hier wurde der v-förmige Einlass und die Rundung beibehalten, da so der Ball am besten fixiert werden kann.

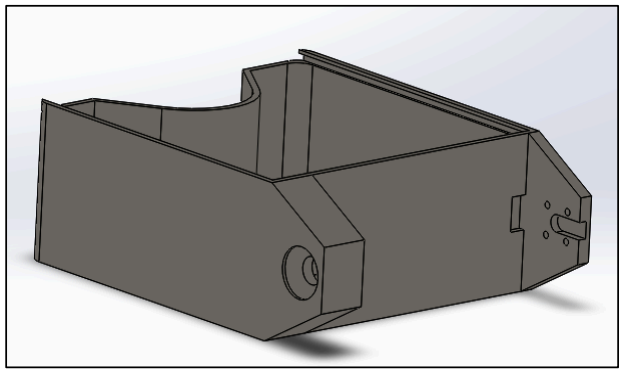
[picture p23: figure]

Abbildung 4: Verbauung der Walze
In Abbildung 4 ist die Verbauung der Walze zu sehen. Der Motor, der zum Antrieb der Walze benötigt wird, wird auf der rechten Seite verbaut und am Chassis mithilfe von vier M2-Schrauben fixiert.

Des Weiteren ist eine kleine Aussparung an der Rückseite des Grundkörpers zu erkennen, diese dient dem einfachen Verbau der Verkabelung. Auf der linken Seite wird die Walze mit einer Schraube, einer Mutter und einem Kugellager, welche sich im inneren der Walze befinden, verbaut und fixiert. Zuletzt ist noch eine Nut an der Oberkante des Chassis zu erkennen, welche dem einfachen Verbau des Deckels dienen soll. Somit ist auch ein schneller Akkuwechsel, falls benötigt, gewährleistet.

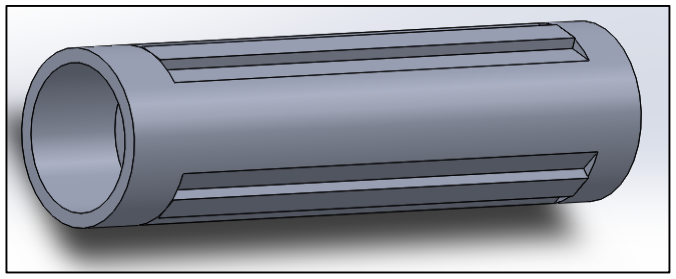
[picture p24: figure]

Abbildung 5: Zusatzanbau Walze Prototyp
Abb. 5 zeigt die Walze in der Komplettansicht. Auf der Außenseite der Walze wurden zusätzlich längliche Rillen konstruiert, welche die „Zerstörungskraft“ der Walze erhöhen sollen und es so leichter machen, den Gegner zu treffen und ihn zu verwunden.

2.3 Bauteilevolution

2.3.1 Chassis
Nach der Fertigstellung des Prototyps und dem letztlichen Wiegen wurde ersichtlich, dass die Gewichtsgrenze von 220 g um ca. 40 g überschritten wurde. Beim Vergleich der Bauteile im Hinblick auf das Gewicht fiel auf, dass das Chassis mit 91 g mitunter am meisten Einsparpotential bot. Wie im Vergleich der Abb. 4 & Abb. 6 zu sehen ist, wurde deshalb die Wanddicke des Grundkörpers an allen vier Seiten reduziert.


Abbildung 6: Leichtbau des Grundkörpers
Um keine Einbußen bei der Stabilität zu verzeichnen, wurden nur ausgewählte Bereiche der Seiten auf 1 mm, anstatt zuvor auf 2mm, reduziert und mit einer Phase versehen. Dadurch, dass nicht die gesamte Fläche dünner konstruiert wurde, sondern noch eine Verstrebung, sowie der Rand mit 2mm erhalten blieb, verschlechterte sich die Stabilität nahezu gar nicht. Darüber hinaus wurden Materialeinsparungen hinten, bei den Halterungen für die Walze, vorgenommen. Auf der linken Seite des Kugellagers lassen sich zwei Dreiecke erkennen, an welchen die Materialeinsparung vorgenommen wurde.
Im Inneren des Chassis-Bauteils wurde, wie in Abb. 7 zu erkennen ist, eine Art Schutzvorrichtung entworfen. Diese hat den Zweck, eine Berührung der Räder mit den Kabeln der Elektronik auszuschließen.


Abbildung 7: Radkasten Draufsicht

Im Laufe des Projekts wurden die zur Befestigung der Räder genutzten M8 Schrauben durch M4-Schrauben ersetzt, um eine Gewichtsreduktion herbeizuführen. Auch hier mussten mittels SolidWorks Anpassungen am Chassis-Bauteil vorgenommen werden und an der Walze ein Stützring, eingefügt werden.

2.3.2 Walze
Bei der als Waffe dienenden Walze war zunächst geplant Aluminium als Werkstoff zu nutzen. Jedoch wurde darauf verzichtet, da Aluminium viel schwerer als der für den 3D-Druck verwendete Kunststoff PLA ist und zudem die Rahmenbedingung besteht, lediglich mit Hilfe des 3D-Drucks zu arbeiten. Somit ist das Bearbeiten eines Bauteiles aus Aluminium mit Hilfe einer Drehmaschine untersagt. Zudem waren die ersten Überlegungen, anstelle der Ausprägungen, im weiteren Verlauf „Nupsis“ genannt, mehrere Schrauben durch die Walze zu schrauben, welche die Zerstörungskraft der Waffe durch die Rotation umsetzen sollte. Dieser Ansatz wurde jedoch aufgrund der Tatsache fallen gelassen, dass das verwendete PLA bei einer zu hohen Drehzahl und dem Kontakt der Schraube mit z.B. dem gegnerischen Roboter schlicht nicht Stand halten würde. Aufgrund dessen wurden Ausprägungen an der Walze realisiert, wie in Abb. 5 und Abb. 8 zu sehen ist. Diese Ausprägungen sollen in Verbindung mit einer hohen Drehzahl der Walze dazu führen, dass ein etwaiges gegnerisches Objekt bei Berührung Schaden nimmt.


Abbildung 8: Überarbeitetes Konzept der Walze

Für den Prototypen wurden zunächst drei Nupsis in die Walze konstruiert. Anhand von Testdrucken, welche im nachfolgenden Kapitel näher beleuchtet werden, entstand zudem die Erkenntnis, dass die Nupsis einer größeren Ausprägung bedürften, also mehr aus der Walze herausragen sollten, sodass die Walze bei Berührung mehr Kraft auf das gegnerische Objekt ausüben kann. Zudem wurde die Anzahl der Nupsis von zunächst drei, beim Prototyp, auf letztendlich fünf erhöht, da dies mehr Zerstörungskraft versprechen soll.

Wie im Vergleich der Abb. 9 & Abb. 11 zu erkennen ist, wurde auf der linken Seite, wo später der Motor sitzen wird, eine Aussparung hinzugefügt. Diese Aussparung sorgt dafür, dass der Motor besser in der Walze sitzt.


Abbildung 9: Überarbeitetes Konzept Innenleben Walze

Die Kegelartige Form in Abb. 9 erfüllt den Zweck der Gewichtseinsparung. Durch den größeren Freiraum besteht die Walze schlicht aus weniger Material. Zudem musste aufgrund des 3D-Druckers eine Trichterform gewählt werden, da ein durchgehender Freiraum nicht hätte gedruckt werden können. Neben dem Chassis-Bauteil, sowie der Waffe, wurde ein weiteres Teil zur Fixierung des Kugellagers benötigt.
Wie in Abb. 12 zu erkennen ist, ist die Walze mit dem Chassis auf der Seite des Kugellagers durch eine Schraube verbunden. Der Innendurchmesser des Kugellagers war zunächst weitaus größer als der Außendurchmesser der Schraube, was dazu geführt hätte, dass die Schraube ein zu hohes Spiel und die Walze bei Rotation einen zu hohen Umschwung gehabt hätte. Deshalb musste, wie in Abb. 10 zu erkennen ist, für das Innere des Kugellagers ein


zusätzliches Bauteil konstruiert werden, welches exakt dem Außendurchmesser des Gewindes der Schraube entspricht und das zuvor herrschende Delta der Durchmesser eliminiert.


Abbildung 11: Altes Konzept Innenleben Walze

Abbildung 10: Stützring

2.4 Gewichtsübersicht
Ein wichtiger Faktor, den es zu beachten galt, war das Gewicht. Der Zusatzanbau wurde nicht, wie zuerst angenommen, aus Aluminium gefertigt. Stattdessen wurde er aus PLA hergestellt, somit ist mit einem geringen Gewicht zu rechnen. Bei der Konstruktion des Roboters in SolidWorks wurde der zum Drucken genutzte Werkstoff eingetragen. So konnte, mithilfe des Programmes eingeschätzt werden, wie viel die jeweiligen Bauteile wiegen und ob das zulässige Gesamtgewicht eingehalten wird. Diejenigen Bauteile, die nicht gedruckt werden müssen (z.B. Räder, Platine), wurden bereits im Vorfeld gewogen. In der folgenden Tabelle wurden alle Bauteile des Ant-Bots inklusive ihres Gewichts aufgelistet.
Baugruppe | Element | Anzahl | Material | Gewicht (gr.)
Waffe | Walze | 1 | PLA | 30,5
| Mutter M5 | 1 | Stahl | 1
| Mutter M8 | 1 | Stahl | 4
| Schraube M8 | 1 | Stahl | 12
| Wechselstrommotor | 1 | | 17
| Kugellager | 1 | Stahl | 1
| Schraube M2 | 4 | Stahl | 1
Grundkörper | Grundkörper | 1 | PLA | 91
| Deckel | 1 | PLA | 15
Elektronik | Akku | 1 | | 36
| Platinen inkl. Kabel | | | 10
Antrieb | Gleichstrommotor | 2 | | 20
| Polulu Rad | 2 | | 8
| Stützrad | 1 | | 9
| Schraube M4 | 4 | Stahl | 1,5
| Mutter M4 | 4 | | 2
| | | Gesamtgewicht | 259

Tabelle 1: Gewichtsübersicht auf Basis des Prototyps

Anhand der Tabelle ist zu erkennen, dass das zulässige Gesamtgewicht von 220 g überschritten wurde. Das liegt vor allem am hohen Gewicht des Chassis und der Walze. Mit insgesamt knapp 40 g Übergewicht musste vor allem das Gewicht des Chassis reduziert werden. Zudem gab es Einsparpotentiale bei der Schraube sowie der Mutter für die Walze.

Baugruppe | Element | Anzahl | Material | Gewicht (gr.)
Waffe | Walze | 1 | PLA | 17
| Mutter M5 | 1 | Stahl | 1
| Mutter M4 | 1 | Stahl | 1
| Schraube M4 | 1 | Stahl | 2
| Wechselstrommotor | 1 | | 17
| Kugellager | 1 | Stahl | 1
| Schraube M2 | 4 | Stahl | 1
Grundkörper | Grundkörper | 1 | PLA | 60
| Deckel | 1 | PLA | 15
Elektronik | Akku | 1 | | 36
| Platinen inkl. Kabel | | | 11,5
Antrieb | Gleichstrommotor | 2 | | 20
| Polulu Rad | 2 | | 8
| Stützrad | 1 | | 9
| Schraube M4 | 4 | Stahl | 1,5
| Mutter M4 | 4 | | 2
| | | Gesamtgewicht | 203

Tabelle 2: Gewichtsübersicht nach Überarbeitung der Bauteile

Die obige Tabelle zeigt die Gewichtsübersicht nach der Überarbeitung der Bauteile. Wie im vorherigen Teil des Berichts bereits thematisiert wurde, wurden die M8-Mutter sowie die M8-Schraube durch eine M4-Mutter und eine M4-Schraube ersetzt.
Das neue Gewicht der Schraube beträgt 2 g, das der Mutter 1 g. Dadurch ergibt sich eine Gesamteinsparung von 13 g. Durch die partielle Reduzierung der Wanddicken des Chassis auf 1 mm konnte auch hier das Gewicht von 91 g auf 60 g verringert werden. Die letzte Gewichtsreduzierung wurde an der Walze vorgenommen. Diese wurde teilweise von innen ausgehöhlt, wie in Absatz 2.4.3 bereits erläutert. Mithilfe dieses Schrittes konnte das Gewicht der Walze von 30,5 g auf 17 g verringert werden. Somit ergibt sich ein neues Gesamtgewicht von 203 g, welches damit unter der Gewichtsgrenze liegt.

## 3 Endergebnis


Abbildung 12: Finaler Roboter der Ant-Klasse

Wie sich aus Abb. 12 erkennen lässt, ist am hinteren Teil des Roboters die Walze angebracht, welche später durch den Joystick einer Fernbedienung zur Rotation gebracht werden kann. Es kann zudem die Geschwindigkeit und Drehzahl pro Minute, sowie die Dauer der Rotation selbst beeinflusst werden.
Ziel ist es, den gegnerischen Roboter mit Hilfe dessen auszuschalten oder ihm zumindest Schaden zuzufügen. Der vordere Teil des Roboters lässt eine V-Form erkennen, welche die Ballführung beim Wettkampf mit dem anderen Roboter darstellt. Durch diese wird es möglich sein, die Tischtennisbälle gezielt in die gewünschte Richtung zu transportieren. Der Deckel des Roboters, welcher in Abb. 12 zur Übersichtlichkeit transparent dargestellt ist, sitzt durch eine Nutführung fest am Chassis und kann problemlos entfernt werden. Dies ermöglicht es, den Roboter zu öffnen und den Akku zu wechseln, sollte dieser leer oder defekt sein.
Im Inneren des Roboters befinden sich zudem die restlichen Elektronikbauteile, bestehend aus: dem Empfänger, den Getriebemotoren für die Räder und dem Brushless Außenläufer der Walze sowie deren Regler, den Kondensatoren, dem Hauptregler und dem Akku. Weiter befinden sich hier die Räder, welche durch eine Halterung fixiert sind. Das Chassis in Abb. 13 bildet das Fundament des Roboters und wurde als ein Bauteil gedruckt. Es war also nicht nötig, mehrere Einzelteile zu drucken und diese durch Fertigungsverfahren der Kategorie Fügen, wie z.B. Kleben, zu verbinden. Lediglich die Halterung der Räder erforderte ein weiteres Bauteil, welches durch eine Schraubverbindung fixiert wurde.


Abbildung 13: Explosionszeichnung Endergebnis
Bauteildefinition von unten nach oben:
1. Walze inkl. Kugellager und Motor
2. Schrauben und Mutter
3. Stützkugel (3. Rad)
4. Chassis-Bauteil
5. Muttern zur Befestigung
6. Antriebsmotoren Räder
7. Polulu-Räder
8. Halterung zur Befestigung der Räder inkl. Schrauben
9. Akku
10. Deckel

## 4 Elektrischer Schaltplan


Abbildung 14: Elektronischer Schaltplan

In der oben gezeigten Abb. 14 ist der elektronische Schaltplan des Roboters zu sehen. An beide Getriebemotoren wurden jeweils drei Kondensatoren angeschlossen, welche hochfrequente Störsignale leiten, um damit elektromagnetische Störungen herabzusetzen. Beide wurden mit dem Hauptregler verbunden. Die beiden gelben Kabel, die vom Hauptregler in den Empfänger gehen sind für die Kanäle eins und zwei, welche für die Ansteuerung der beiden Getriebemotoren zuständig sind. Kanal drei dient der Ansteuerung des Außenläufermotors der Walze. Beim roten sowie dem schwarzen Kabel, das vom Hauptregler in den Empfänger geht, handelt es sich um stromführende Kabel. Das schwarze Kabel ist hierbei das (-)-Kabel und das Rote ist das (+)-Kabel. Selbiges gilt auch für die beiden Kabel die vom Hauptregler aus in den zweiten Regler gehen.

## 5 Testdrucke

Testdrucke waren nicht nur im Hinblick auf die Optimierung des Gewichtes wichtig, sondern auch für die als Waffe dienende Rolle sind sie unerlässlich. Dadurch, dass die Walze ein Kugellager, sowie einen Motor in sich verbaut hat, war es enorm wichtig, den Innendurchmesser, der als Passung dienenden Ausprägungen, exakt zu wählen. Schon geringe Abweichungen können dazu führen, dass die Bauteile entweder zu lose in der Rolle sitzen oder gar nicht hineinpassen. Zudem verfügt die Rolle ihrerseits über Ausprägungen, welche dafür sorgen sollen, die Kraft, welche bei der Rotation entsteht auf den gegnerischen Roboter zu übertragen und Schaden anzurichten. Auch hier war es wichtig, die Größe der Nupsis genau zu bestimmen, um größtmöglichen Schaden mit der Rolle verursachen zu können. Nachdem festgestellt wurde, dass die Innendurchmesser der Ausprägungen für Motor und Kugellager bei den ersten Drucken zu groß gewählt waren, wurden Anpassungen vorgenommen und der Durchmesser leicht verkleinert. Natürlich muss zudem darauf geachtet werden, dass das Zusammenführen der Bauteile unter gleichen Bedingungen geschieht, da eine unterschiedliche Raumtemperatur zu Ausdehnungen oder Verkleinerung bei den Bauteilen führen kann. Durch die Testdrucke wurde zudem klar, dass jeder Drucker individuell ist und Abweichungen bei den Maßen der gedruckten Bauteile auftauchen können. Der Testdruck und der finale Druck für ein bestimmtes Bauteil, sollten aus diesem Grund stets mit dem gleichen Drucker erfolgen.

## 6 Projektfazit

Das Konstruieren, Entwerfen, 3D-Drucken und letztlich das Zusammenbauen eines Roboters der Ant-Klasse stellte mit seiner Vielfältigkeit an Herausforderungen ein sowohl sehr anspruchsvolles, wie auch spannendes Projekt dar. Eine, und die wohl zugleich auch größte Herausforderung des Projektes war es, eine sinnvolle Projektplanung zu realisieren. Aufgrund der hohen Komplexität und des Projektumfanges war eine gute Koordination der Aufgaben, eine hohe Kommunikation innerhalb der Gruppe, sowie ein klarer Terminplan ausschlaggebend für den späteren Erfolg oder Misserfolg des Projektes.

Durch regelmäßige Treffen, eine klare Aufgabenverteilung innerhalb der Gruppe, sowie der Erarbeitung eines Terminplanes in Form eines Gant-Diagrammes, war es möglich eine hohe Teamdynamik zu entwickeln. Diese ermöglichte es letztendlich, selbst gesteckte Ziele und Meilensteine zum geplanten Zeitpunkt zu erreichen und unvorhergesehene Hürden, wie z.B. das Gewichtsproblem, zu überwinden. Die Erkenntnisse aus der engen Teamarbeit waren nicht nur für das Projekt selbst ein enormer Vorteil, sondern lassen sich ebenso auf die Arbeitswelt übertragen. Hierbei sind weniger projektspezifische Inhalte, wie das Konstruieren mit SolidWorks oder das Arbeiten mit dem 3D-Drucker gemeint, sondern vielmehr eine analytische und strukturierte Denkweise erforderlich. Diese stellen die Grundlage für ein erfolgreiches Projekt dar. Besonders exemplarisch ist hier der Projektbeginn zu erwähnen, bei welchem es vor allem darum ging, einen komplexen Sachverhalt zu analysieren und ein passendes Konzept zu entwickeln, welches eine optimale Lösung für die Aufgabenstellung darstellt. Wäre während dieser Phase nicht genau und sorgfältig gearbeitet worden, so wäre das gesamte Projekt durch diverse plötzlich auftretende Probleme gezeichnet gewesen, was zu späten Änderungen und einem deutlichen Mehraufwand geführt hätte. Eine weitere Herausforderung, welche bereits zu Beginn des Projektes auftrat, war es sich zunächst eine geeignete Waffe zu überlegen. Diese sollte sowohl mit den vorhandenen Ressourcen umsetzbar, jedoch zeitgleich auch einen tatsächlichen Nutzen mit sich bringen. Nach langem recherchieren im Internet, brainstormen und dem Abwägen der Möglichkeiten fiel die Entscheidung schließlich auf eine Walze, welche im Laufe des Berichtes bereits beschrieben wurde. Andere Möglichkeiten, wie ein Hebearm oder eine Umwerfvorrichtung wurden aufgrund der Komplexität und des Gewichtes nicht in Erwägung gezogen. Die nächste große Hürde des Projektes stellte die Gewichtsbeschränkung von 220 g dar, welche durch evaluieren und optimieren der Bauteile beim Konstruieren überwunden werden konnte. Mithilfe von Tutorials erfolgte eine problemlose und zügige Einarbeitung und erleichterte den Umgang mit der SolidWorks Software sowie dem 3D-Drucker.

Durch das Programm GitHub und das kontinuierliche Abstimmen darüber, wer für welches Bauteil zuständig ist, konnte zudem ein effizientes Arbeiten sichergestellt und etwaige Datenredundanzen vermieden werden.
Ferner lässt sich sagen, dass das Projekt durch seine vielfältigen Aufgaben und Facetten für jedes Gruppenmitglied neue Erkenntnisse mit sich gebracht hat. Darüber hinaus konnte ein klarer Mehrwert geschaffen werden. Dadurch, dass man während des Projektes die gesamte Produktentwicklung des Roboters durchlief, entstand ein einheitlicher Überblick des Fertigungsprozesses.

2019
März | Mai | Juni | Juli
Aktivität | KW13 | KW14 | KW15 | KW16 | KW17 | KW18 | KW19 | KW20 | KW21 | KW22 | KW23 | KW24 | KW25 | KW26
Interpretation der Aufgabenstellung Rückfragen bez. Ablauf des Projektes + Rücksprache mit Projektleitung Festlegen der Ansprüche und Ziele
Projektbesprechung zur Analyse Brainstorming Aufbau des Roboters Erstellung Morphologischer Kasten Aufteilung Aufgaben Workshop GitHub und 3D-Druck Erstellung Zeitplan und Projektablauf Ausarbeitung Analyse des Projektes Beginn Dokumentation | | 03/04/19 03/04/19 03/04/19
Präsentation der Analyse Beginn Erarbeitung eines Konzeptes Beginn Dokumentation GitHub Beginn konstruieren mit SolidWorks | | 10/04/19
Projektbesprechung zum Konzept | | 17/04/19
Präsentation Konzept + Abgabe ZWB Einarbeitung in den 3D-Druck Umsetzung des Konzeptes Iterative Optimierung des Prototypen | | 24/04/19
Projektbesprechung zum Prototyp | | | 15/05/19 22/05/19
Fachgespräche zum Prototyp

Projektbesprechung zur Umsetzung
Projektbesprechung zur wissenschaftl. Ausarbeitung und Endpräsentation | 29/05/19

Löten von Elektrokomponenten Finales Drucken der Komponenten

Erste Testdrucke (Gewichtsstruktur)

Montage der Komponenten

26/06/19

05/06/19

Kickoff Projekt | Finale Präsentation
27/03/19

## Anhang

Morphologischer Kasten:

Parameter | Ausprägungen
Antrieb | Zwei Räder vorne breit, SR hinten | Zwei Räder vorne eng, SR hinten
Größe | 10x10x10 cm inkl. Anbauten | 10x10x10 cm exkl. An-bauten
Zusatzanbauten | Greifer | Umwerfvorrichtung | Drehendes Ele-ment
Ballführung | Dreieck (V-Form) | Seitliche Führung | Runde Führung | Dreieck und Rund kombiniert
Gewicht | 150 g | zw. 150 g – 220 g | 220 g
Form Chassis | Quadratisch | Dreieckig | Mehreckig | Rund
Verschlussart Rahmen | Schrauben | Stoffschlüssig | Steckverbindung | Formschlüssig
Zusatzanbauten Material | Plastik | Metall | Holz
Schwerpunkt | Vorne | Hinten | Mittig
Akkueinbau | Schnell wechselfähig

Projektterminplan:

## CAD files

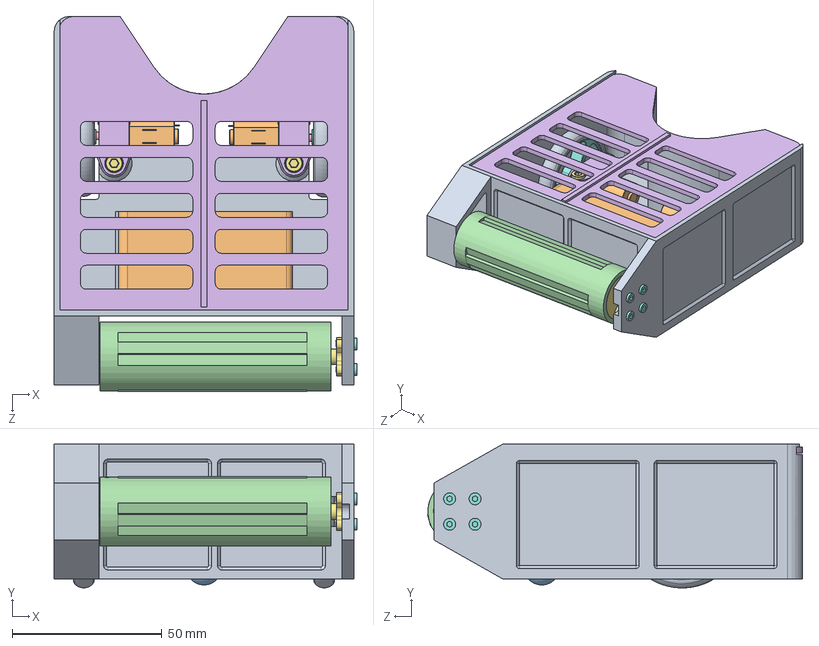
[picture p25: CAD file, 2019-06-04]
CAD-Daten/Baugruppe/Baugruppe_2.SLDASM
101.0 x 48.0 x 125.1 mm
Chassi_7 (Leichtbau geschlossen)
V-Tec_MicroMotor_6V x 2
V-Tec_GetriebePlatteMockup x 6
V-Tec_DistanzRohr x 8
V-Tec_AntriebsWelle x 2
V-Tec_GetriebeHalter x 2
Screw M3 DIN 912 x 4
Pololu_Wheel_40x7_Felge x 2
PololuWheel_40x7_Reifen x 2
KugelAufnahme
Kugel 12mm
Walze_2
Kugellager
Nut M5
Motor
Screw M2 x 4
Akkuhalterung
Lipo_2S_350mA_LemonRC
Nut M4 DIN 934
Screw M4 DIN 7991
Nut M3 DIN 934 x 4
Deckel_3

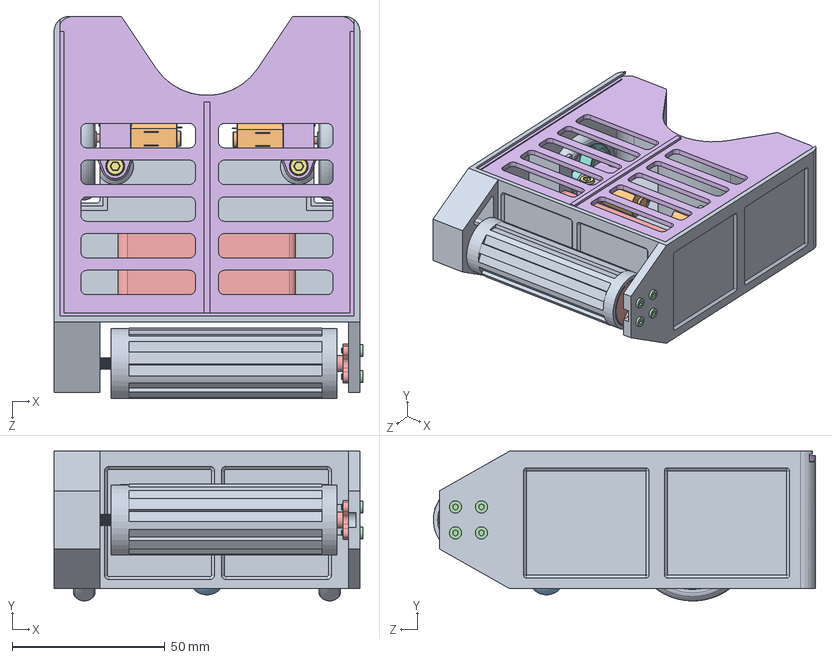
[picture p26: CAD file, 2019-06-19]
CAD-Daten/Final Version/Baugruppe_Final.SLDASM
101.0 x 49.0 x 125.0 mm
Chassi_Final
V-Tec_MicroMotor_6V x 2
V-Tec_GetriebePlatteMockup x 6
V-Tec_DistanzRohr x 8
V-Tec_AntriebsWelle x 2
V-Tec_GetriebeHalter x 2
Screw M3 DIN 912 x 4
Pololu_Wheel_40x7_Felge x 2
PololuWheel_40x7_Reifen x 2
KugelAufnahme
Kugel 12mm
Screw M2 x 4
Lipo_2S_350mA_LemonRC
Nut M4 DIN 934
Screw M4
Nut M3 DIN 934 x 4
Walze_Final
Kugellager
Hülse_Final
Nut M5
Motor
Deckel_Final

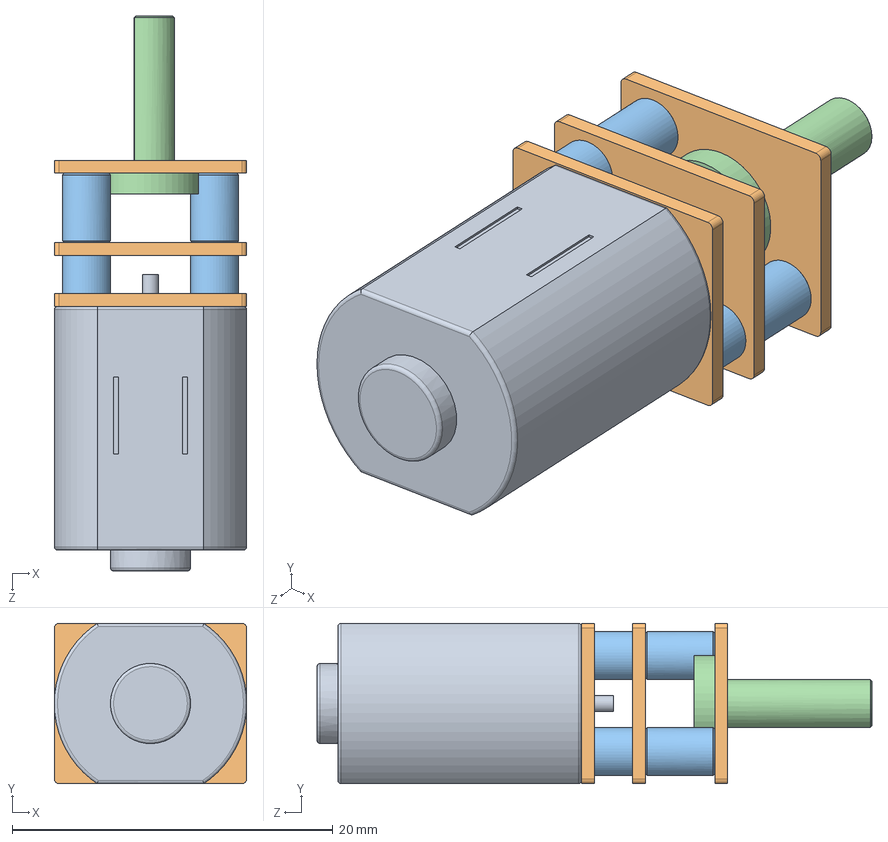
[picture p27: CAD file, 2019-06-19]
CAD-Daten/Final Version/V-Tec_MotorEinheit.SLDASM
12.0 x 10.0 x 34.6 mm
V-Tec_MicroMotor_6V
V-Tec_GetriebePlatteMockup x 3
V-Tec_DistanzRohr x 4
V-Tec_AntriebsWelle

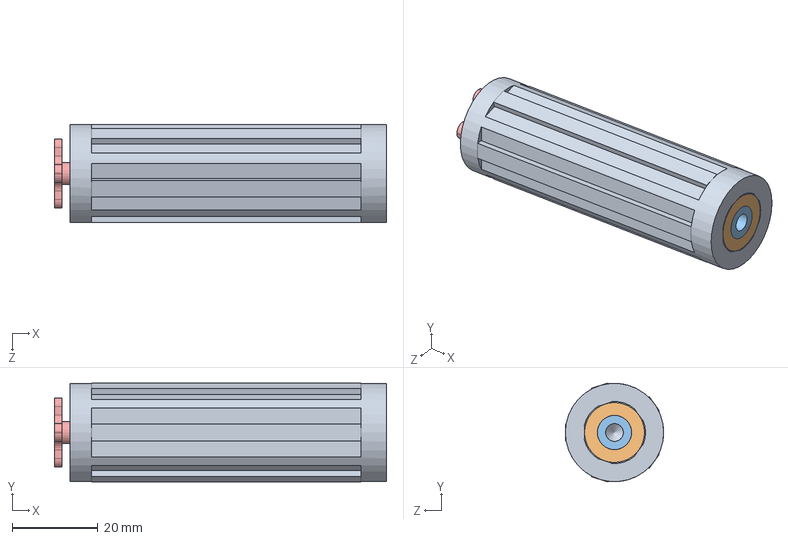
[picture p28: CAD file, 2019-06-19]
CAD-Daten/Final Version/Waffe_Final.SLDASM
77.7 x 23.1 x 23.0 mm
Walze_Final
Kugellager
Hülse_Final
Nut M5
Motor

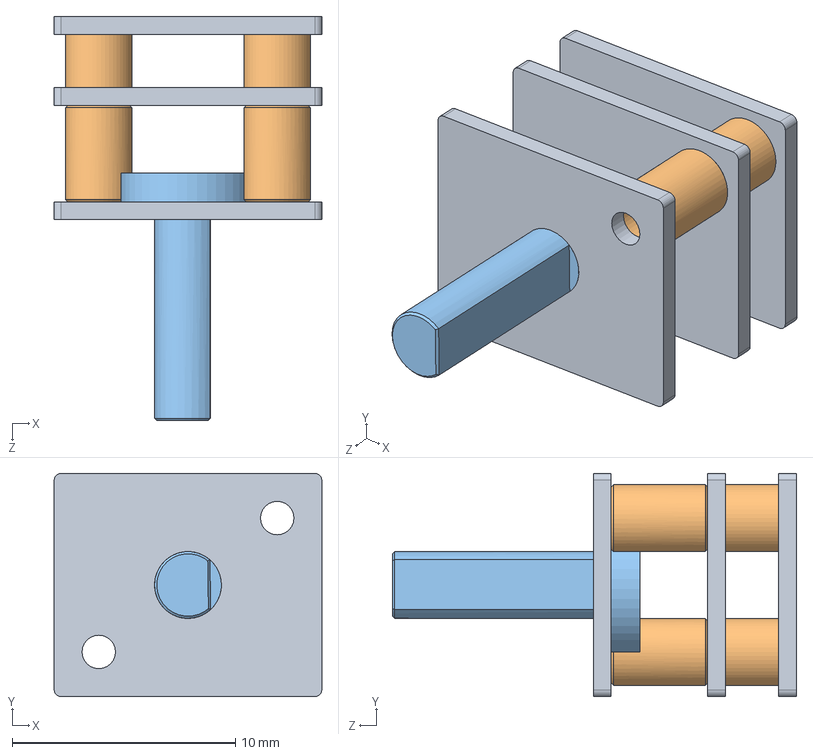
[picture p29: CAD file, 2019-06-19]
CAD-Daten/Final Version/V-Tec_GetriebeMockup.SLDASM
12.0 x 10.0 x 18.1 mm
V-Tec_GetriebePlatteMockup x 3
V-Tec_DistanzRohr x 4
V-Tec_AntriebsWelle

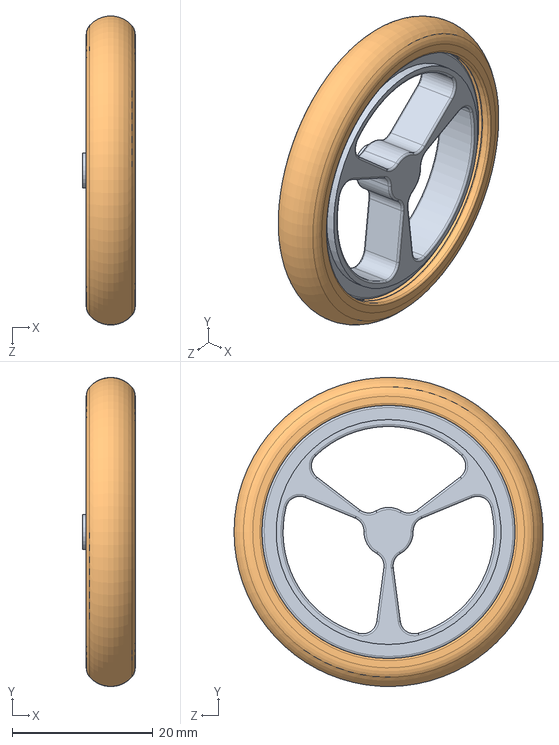
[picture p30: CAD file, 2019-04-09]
CAD-Daten/Final Version/PololuWheel_Rad_links.SLDASM
7.50 x 44.0 x 43.9 mm
Pololu_Wheel_40x7_Felge
PololuWheel_40x7_Reifen

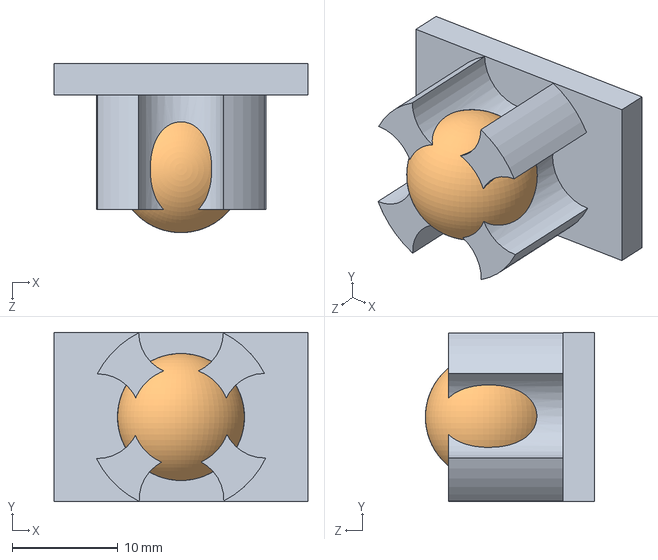
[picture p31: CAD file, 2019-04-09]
CAD-Daten/Final Version/KugelRoller.SLDASM
24.0 x 16.0 x 16.0 mm
KugelAufnahme
Kugel 12mm

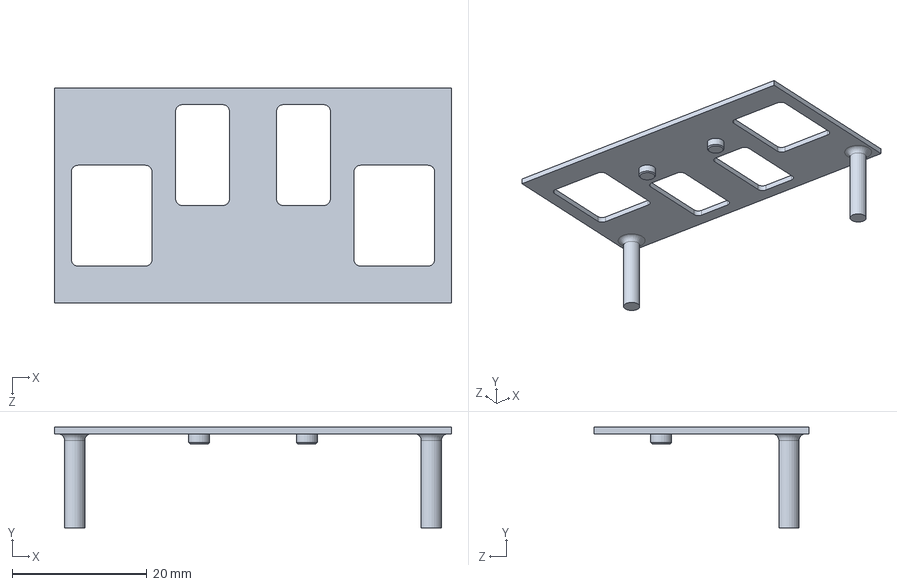
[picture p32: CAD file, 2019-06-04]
CAD-Daten/Akku/Akkuhalterung.SLDPRT
59.0 x 15.0 x 32.0 mm

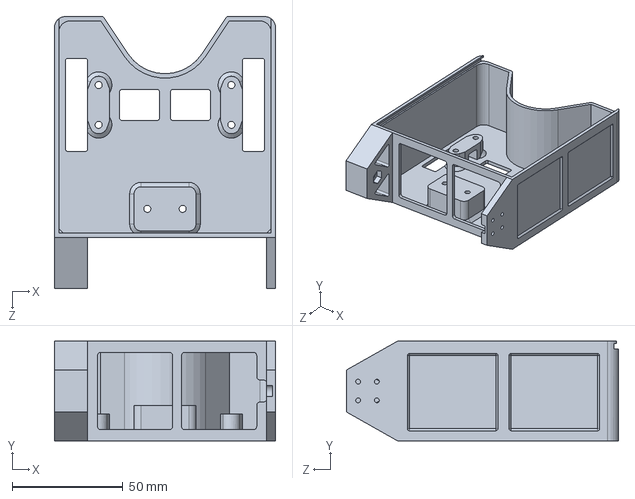
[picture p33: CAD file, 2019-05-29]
CAD-Daten/Chassi/Chassi_6 (Leichtbau offen).SLDPRT
100.0 x 45.0 x 123.0 mm

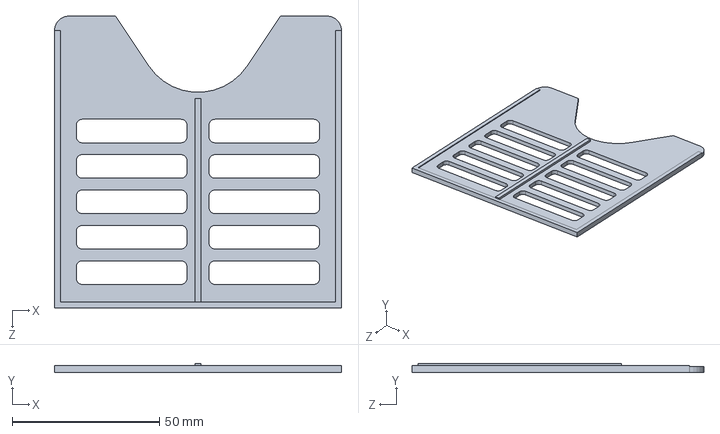
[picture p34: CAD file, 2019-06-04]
CAD-Daten/Deckel/Deckel_4.SLDPRT
97.4 x 3.00 x 99.0 mm

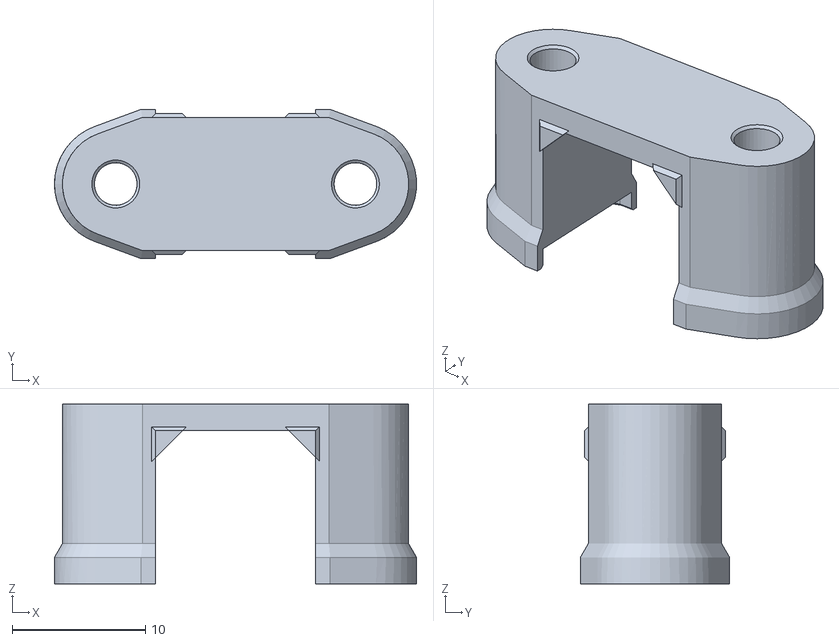
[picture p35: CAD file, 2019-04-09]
CAD-Daten/Getriebemotor/V-Tec_GetriebeHalter.STL
27.2 x 11.2 x 13.5

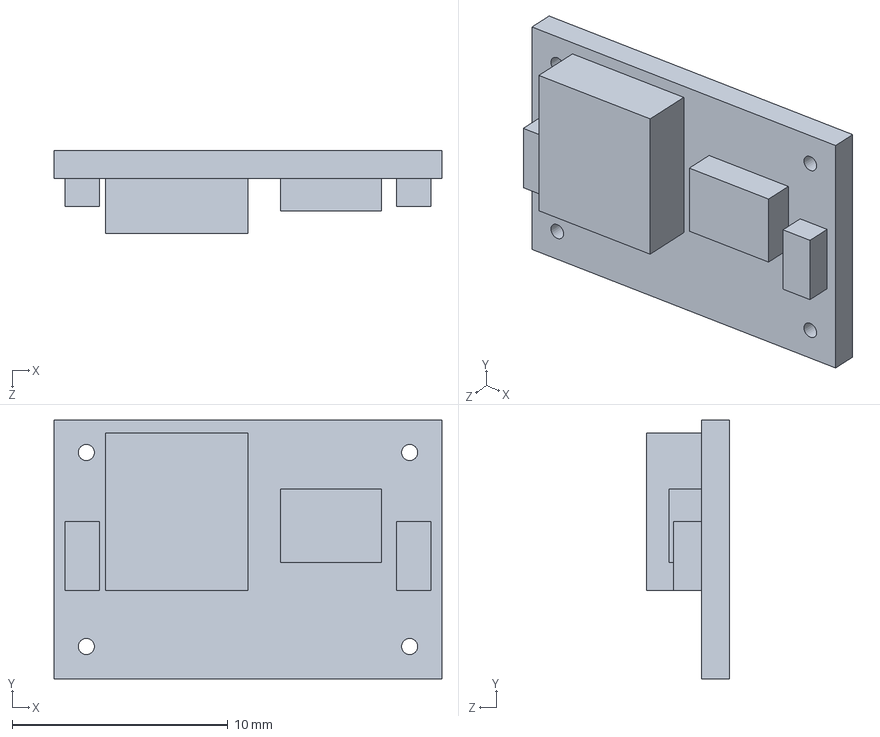
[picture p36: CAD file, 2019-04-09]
CAD-Daten/Speed Controller/BEC 5V 2A Diatone V2 DT-EL0011.SLDPRT
18.0 x 12.0 x 3.85 mm

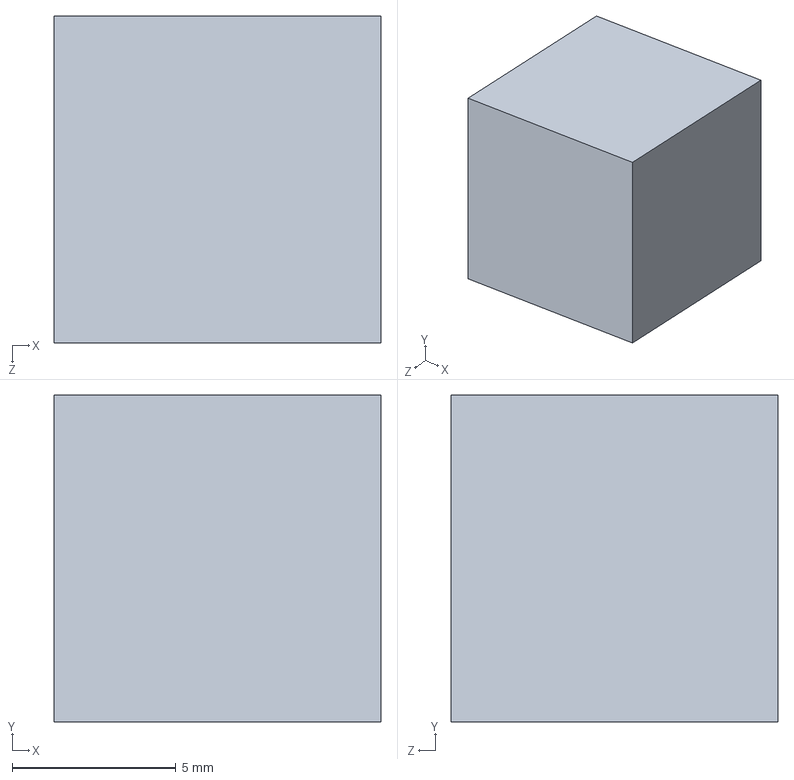
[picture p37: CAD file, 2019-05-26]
CAD-Daten/Testdruck für Massenbestimmung.SLDPRT
10.0 x 10.0 x 10.0 mm

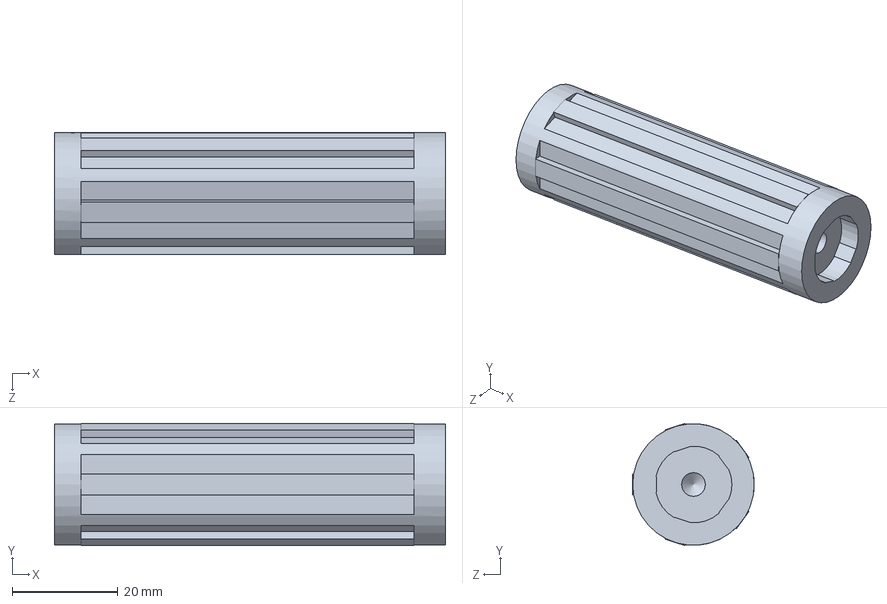
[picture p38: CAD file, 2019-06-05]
CAD-Daten/Waffenelement/Walze_7.SLDPRT
74.0 x 23.1 x 23.0 mm

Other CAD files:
CAD-Daten/Baugruppe/Baugruppe.SLDASM
CAD-Daten/Chassi/Chassi_7 (Leichtbau geschlossen).SLDPRT
CAD-Daten/Deckel/Deckel_3.SLDPRT
CAD-Daten/Akku/Akkuhalterung.STL
CAD-Daten/Chassi/Chassi_1.SLDPRT
CAD-Daten/Chassi/Chassi_2.SLDPRT
CAD-Daten/Chassi/Chassi_3.SLDPRT
CAD-Daten/Chassi/Chassi_4.SLDPRT
CAD-Daten/Chassi/Chassi_5 (Schraubenänderung).SLDPRT
CAD-Daten/Deckel/Deckel_1.SLDPRT
CAD-Daten/Deckel/Deckel_2.SLDPRT
CAD-Daten/Deckel/Deckel_4.STL
CAD-Daten/Final Version/Chassi_Final.SLDPRT
CAD-Daten/Final Version/Chassi_Final.STL
CAD-Daten/Final Version/Deckel_Final.SLDPRT
CAD-Daten/Final Version/Hülse_Final.SLDPRT
CAD-Daten/Final Version/Kugel 12mm.SLDPRT
CAD-Daten/Final Version/KugelAufnahme.SLDPRT
CAD-Daten/Final Version/Kugellager.SLDPRT
CAD-Daten/Final Version/Lipo_2S_350mA_LemonRC.SLDPRT
CAD-Daten/Final Version/Motor.SLDPRT
CAD-Daten/Final Version/Nut M3 DIN 934.SLDPRT
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

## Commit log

2019-04-08 Create file
    Dieser Ordner ist für sämtliche CAD-Daten gedacht.
2019-04-09 SolidWorks-Komponenten hinzugefügt
    [BEC 5V 2A Diatone V2 DT-EL0011.SLDPRT, Kugel 12mm.SLDPRT, KugelAufnahme.SLDPRT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]
2019-04-24 CAD Daten hinzugefügt
    [V-Tec_AntriebsWelle.SLDPRT, V-Tec_DistanzRohr.SLDPRT, V-Tec_GetriebeHalter.SLDPRT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]
2019-04-24 CAD Daten eingefügt
    [Lipo_2S_350mA_LemonRC.SLDDRW, Lipo_2S_350mA_LemonRC.SLDPRT]
2019-05-06 Grundkörper
    Stand 6. Mai: Grundkörper + Vorrichtung Motor
    [Grundkörper.SLDPRT]
2019-05-07 Komplettteil hinzugefügt
    [Komplett Teil.SLDASM]
2019-05-19 Teil mit Stützkugel
    Stützkugel wurde hinzugefügt
    [Komplett Teil.SLDASM]
2019-05-19 Ausparung für Stützkugel
    [Grundkörper.SLDPRT]
2019-05-19 Akkuhalterung Innen
    [Akkuaufsatz.SLDPRT]
2019-05-19 Schraube für Kugellager
    [Screw M8.SLDPRT]
2019-05-19 M2 Schraube Motorbefestigung
    [Screw M2.SLDPRT]
2019-05-19 Mutter M8
    [Nut M8.SLDPRT]
2019-05-19 verbesserter Grundkörper
    [Grundkörper 2.0.SLDPRT]
2019-05-20 AntBot mit Waffenhalterung
    [Komplett_Teil.SLDASM]
2019-05-20 Walze komplett
    [Walze.SLDPRT]
2019-05-20 Final Version
    [Final_Version.SLDPRT]
2019-05-20 Motor für Waffe
    [Motor.SLDPRT]
2019-05-20 Walze konstruiert
    [Walze.SLDPRT]
2019-05-20 Nut M5
    [Nut M5.SLDPRT]
2019-05-20 Änderung an der Höhe
    [Final_Version.SLDPRT]
2019-05-20 andere Farbe
    [V-Tec_GetriebeHalter.SLDPRT]
2019-05-20 Finaler Prototyp
    [Final.SLDASM]
2019-05-20 Motor angepasst
    [Motor.SLDPRT]
2019-05-20 Kugellager angepasst
    [Kugellager.SLDPRT]
2019-05-20 Walze angepasst
    [Walze.SLDPRT]
2019-05-20 Waffe angepasst
    [Waffe_komplett.SLDASM]
2019-05-21 Walze PLA
    [Walze.SLDPRT]
2019-05-21 Einsparungen am Grundkörper
    [Final_Version - Opti.SLDPRT]
2019-05-21 Einsparungen am Deckel
    [Deckel-Opti.SLDPRT]
2019-05-21 Walze verändert
    [Walze -Opti.SLDPRT]
2019-05-21 Änderungen vorgenommen
    [Waffe_komplett.SLDASM]
2019-05-21 alte Chassientwürfe
    [Chassi_1.SLDPRT, Chassi_2.SLDPRT, Chassi_3.SLDPRT]
2019-05-21 aktueller Stand 21.05
    [Chassi_4.SLDPRT]
2019-05-23 Waffenhalterung auf M4 konstruiert
    [Chassi_5 (Schraubenänderung).SLDPRT]
2019-05-23 Aktueller Stand 23.05
    [Komplettteil_2 (Schraubenänderung auf M4).SLDASM]
2019-05-26 Walze mit M4 konstruiert
    [Walze_neu.SLDPRT]
2019-05-26 Innenring für Kugellager M4
    [Innenring Kugellager.SLDPRT]
2019-05-26 Testdruck Quader 10x10x10 für Massenbestimmung PLA
    [Testdruck für Massenbestimmung.SLDPRT]
2019-05-28 Kugellager Presspassung Testdruck
    [Kugellager Presspassung.SLDPRT]
2019-05-28 M4 Änderung + Leichtbau
    [Chassi_6 (Schraubenänderung+Leichtbau).SLDPRT]
2019-05-28 Dicke von 1,9mm
    [Deckel_3.SLDPRT]
2019-05-28 Änderung auf M4 + Leichtbauweise
    [Chassi_6 (Schraubenänderung+Leichtbau).SLDPRT]
2019-05-29 Kugellager Presspassung STL Testdruck
    [Testdruck Kugellagerpresspassung.STL]
2019-05-29 Schraubenänderung M4+Leichtbau
    [Chassi_6 (Schraubenänderung+Leichtbau).SLDPRT]
2019-05-29 Strebe angefügt
    [Deckel_3.SLDPRT]
2019-06-03 Walze Presspassung
    [Walze_neu mit Nupsis.SLDPRT]
2019-06-03 Hülse für Kugellager
    [Hülse.SLDPRT]
2019-06-04 STL zum 1. Drucken
    [Deckel 3.STL]
2019-06-04 Walze_5 STL zum Druck
    [Walze_5.STL]
2019-06-04 Veränderung an Akkuhalterung
    [Akkuhalterung.SLDPRT, Akkuhalterung.STL]
2019-06-04 Waffe_5 STL Datei
    [Walze_5.STL]
2019-06-04 Hülse_2 STL Datei
    [Hülse_2.STL]
2019-06-04 Hülse_2
    [Hülse_2.SLDPRT]
2019-06-04 Hülse_3 STL
    [Hülse_3.STL]
2019-06-04 Hülse_3
    [Hülse_3.SLDPRT]
2019-06-04 Hülse_4 STL
    [Hülse_4.STL]
2019-06-05 Walze 7 mit 5 Nupsis und Phase
    [Walze_7.SLDPRT]
2019-06-05 Walze 7 mit 5 Nupsis und Phase und Verbreiterung um 0,15mm
    [Walze_7.STL]
2019-06-13 M4 Schraubenloch angepasst und Stützkugel entfernt
    [Chassi_8 (Leichtbau geschlossen).SLDPRT]
2019-06-13 Statt Stützkugel neue Kugel integriert
    [Chassi_9 (Leichtbau geschlossen).SLDPRT]
2019-06-17 Varianten Stützkugelersatz
    [Chassi_10 (ohne Stützkugelvariante).SLDPRT, Chassi_8 (Stützkugelvariante Rechteck).SLDPRT, Chassi_9 (Stützkugelvariante Kugel).SLDPRT]
2019-06-17 Mit Stegstütze
    [Chassi_8.SLDPRT]
2019-06-19 Chassi als STL
    [Chassi_Final.STL]
